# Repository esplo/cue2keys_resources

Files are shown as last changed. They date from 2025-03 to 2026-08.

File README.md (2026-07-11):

# cue2keys_resources

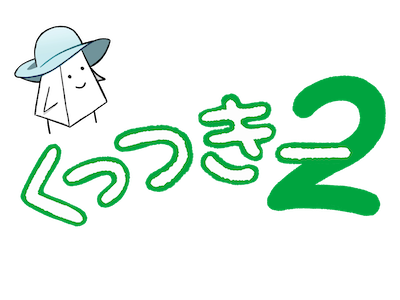
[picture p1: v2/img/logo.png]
ロゴ


このリポジトリでは、[くっつきー](https://cue2keys.esplo.net/)のドキュメントやその他リソースを保管しています。

ここではくっつきーv2のドキュメントを紹介しています。
[初代くっつきーのドキュメントはこちら](./v1/)をご覧ください。

## くっつきーについて知りたい

[紹介記事](https://www.esplo.net/ja/products/cue2keys2)、[公式サイト](https://cue2keys.esplo.net/)や[ビルドガイド](./v2/docs/build_guide.md)をご覧ください。

## 何を組み合わせればよいか知りたい

[購入ガイド](./v2/docs/shopping_guide.md)をご確認ください。

## 購入したので組み立てを知りたい

[ビルドガイド](./v2/docs/build_guide.md)をご覧ください。

## 感想・不具合報告・要望を伝えたい

[SNS](https://x.com/cue2keys)、[マシュマロ](https://marshmallow-qa.com/9p7qcrd1b86zk8d)、このリポジトリの[issue](https://github.com/esplo/cue2keys_resources/issues)、[BOOTHのメッセージ](https://c2k.booth.pm/)などでご連絡ください。

## 挙動を調整したい

くっつきー2用Webアプリをご利用ください。
利用方法はアプリに記載の案内、[ビルドガイド](./v2/docs/build_guide.md)などをご覧ください。

https://app-cue2keys.esplo.net

## リソース一覧

- [ビルドガイド](./v2/docs/build_guide.md)
- [購入ガイド](./v2/docs/shopping_guide.md)
- [困ったときは？](./v2/docs/troubleshoot.md)

- [初代ユーザー向けガイド](./v2/docs/first_user_guide.md)

- [カスタマイズガイド](./v2/docs/customize_guide.md)
- [ファームウェアガイド](./v2/docs/firmware_guide.md)
- [制限・制約](./v2/docs/limits.md)
- [3Dモデル](./v2/docs/models.md)

モジュールの詳細

- [キーモジュール](./v2/docs/modules/keys.md)
- [ディスプレイモジュール](./v2/docs/modules/display.md)

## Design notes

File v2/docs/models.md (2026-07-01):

# 3Dモデル

このページでは、各モジュールの3Dモデルへのリンクをまとめています。
3Dプリンターをお持ちであれば、色変更や交換・カスタマイズなどにご利用ください。

なお、全てネジ不要のはめ込み式なので、フィラメント以外の部品は必要ありません。

## 各モデルへのリンク

全てMakerWorldで公開しています。

- [キー](https://makerworld.com/en/models/2669850-cue2keys-2-key-module-case#profileId-2954925)
- [トラックボール](https://makerworld.com/en/models/2669982-cue2keys-2-trackball-module-case#profileId-2955072)
- [ペンダント](https://makerworld.com/en/models/2978841-cue2keys-2-pendant-module-case#profileId-3341880)
- [ハブ](https://makerworld.com/en/models/2978872-cue2keys-2-hub-module-case#profileId-3341919)
- [ディスプレイ](https://makerworld.com/en/models/2978860-cue2keys-2-display-module-case#profileId-3341903)
- [ノブ](https://makerworld.com/en/models/2978908-cue2keys-2-rotary-encoder-module-case#profileId-3341963)
- [土台](https://makerworld.com/en/models/2978887-cue2keys-2-base#profileId-3341940)
- [土台ケース](https://makerworld.com/en/models/2978878-cue2keys-2-base-case#profileId-3341930)
- [チップ](https://makerworld.com/en/models/2997135-cue2keys-2-chip#profileId-3364564)

## 印刷のTips

- 土台と接触する凹凸部分は、0.12mm以下のLayer heightで印刷してください。Layer Height Modifierを使うと、対象部分だけ個別にLayer heightを設定できます。

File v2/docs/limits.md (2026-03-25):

# モジュール接続の制約

くっつきー2では、モジュールをケーブルで接続することで、数を自由に増減できます。
ただし、基板・電気およびソフトウェアによる制限があります。
このページでは、その詳細を記載します。

## まとめ

最初に簡単なまとめを記載します。
状況により個数は変わるため、一般的な上限値を記載します。
詳細は各項目をご覧ください。

- 最低限動作に必要: ペンダントx1、ハブx1
- ハブ: 最大4つ
- トラックボール: 最大4つ
- キー・マグネキーモジュール合計: 40個
- マグネキーモジュール: （最大精度）10個程度
- 1つのハブ:
  - 最大14個のキー・マグネキー・ノブ・ディスプレイ
  - 1つのトラックボールモジュール
- ノブ: 最大16個
- ディスプレイ: 最大1個
- 初代モジュール:
  - 4キー/5キー/ノブの制約は初代と同じ
  - トラックボールは2の制約と同じ
  - 1つのハブに対し1つの変換モジュールが必要

処理コストが一定を超えると、1秒間に処理できる入力の頻度が減り、タイピングおよびマウスカーソル移動がカクつくようになってしまいます。
マグネキーなど処理の重いモジュールを負荷の高い設定で利用する場合、後述する`処理コストの目安`を参考にしてください。

### 基礎知識

- ペンダントは4つのチャンネルを持つ
- 各チャンネルにはそれぞれ別のハブを接続する
- チャンネル単位での制約、ハブ単位の制約、全体の制約がそれぞれあることに注意

## モジュールごとの制約

### キーの制約

1つのハブにつき、最大14個まで接続できます。
マグネキーは読み取りに時間がかかるため、後述する`処理コストの目安`を参考にしてください。

### ディスプレイの制約

全体で最大1つです。

### トラックボールの制約

1つのチャンネルにつき1つ、全体で4つまで接続できます。
接続にはハブが必要で、1つのハブに1つだけ接続できます。

### ハブの制約

基板には4pinコネクターが14個、6pinコネクターが2個あります。
ただし、6pinコネクターにはどちらか片方のみ接続できます。

物理的に遠い距離に置きたい（左右分割）、別チャンネルを使いたい場合は、複数のハブが必要です。

ハブはカスケード接続をして複数のハブを直列につなぐことも可能ですが、初代モジュール接続以外では非推奨です。

## 処理コストの目安

1秒間に処理できる入力の回数（スキャンレート）は、接続しているモジュールの数や種類によって大きく変動します。
特にマグネキーは高い精度で利用すると処理時間がかかりますので、多く繋ぐ場合はご注意ください。

記載外モジュールの影響（ディスプレイ・トラックボール）、ファームウェアのバージョンやトラックボールの操作有無により変動するため、下記の値は目安としてご利用ください。

- キーモジュール: 0.15ms
- マグネキーモジュール（12bit設定）: 0.27ms
- マグネキーモジュール（8bit設定）: 0.22ms
- マグネキーモジュール（4bit設定）: 0.17ms
- マグネキーモジュール（2bit設定）: 0.15ms
- ロータリーエンコーダー: 0.13ms

なお、スターターセットDXの構成では377回/秒（2.65ms）程度、トラックボールを動かすと347回/秒（2.88ms）となっています。

### 様々な例

ここでは、構成によってスキャンレートがどの程度になるかの例を記載します。
ファームウェアバージョンや操作（トラックボールを動かしたかどうか）で変動しますので、あくまで目安としてご利用ください。

ご要望に応じて追記します。
組み合わせによってはお時間をいただくかもしれませんが、お気軽にご連絡ください。

- （スターターセットDX） キー14個、マグネキー1個、ディスプレイ、ノブ、トラックボール: 377回/秒
-  キー10個、マグネキー6個（12bit）、ディスプレイ、ノブ、トラックボール: 308回/秒

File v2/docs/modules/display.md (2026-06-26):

# ディスプレイモジュール詳解

https://c2k.booth.pm/items/8105221

## 新旧バージョンの違い

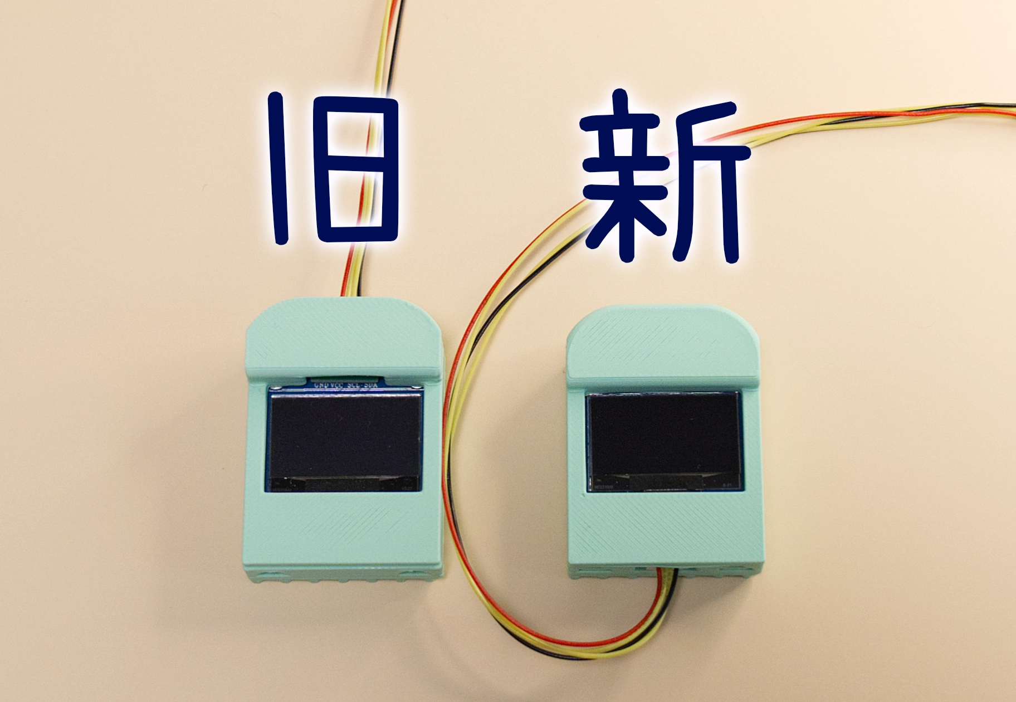
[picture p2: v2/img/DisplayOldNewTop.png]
両バージョン


キーケット後のバージョンでは、製造都合により基板とケースが変更になっております。悪しからずご了承ください。

新バージョンではケーブルが下部から出ているほか、少しだけ高さが減っていたり、ケーブルを通しやすくなっています。

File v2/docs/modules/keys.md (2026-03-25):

# キーモジュール詳解

https://c2k.booth.pm/items/8027041

## キースイッチの変更

一般的なキースイッチプーラーなどを使い、スイッチを取り外して変更してください。

通常キーモジュールは、5pinまたは3pinのCherry MXキースイッチに対応しています。
また、マグネキーモジュールは、KS-20互換であれば動作します。他のキースイッチでも形状が合えば設定で対応できると思いますが、公式サポートにはなりません。小数のキーで試してから入れ替えをお勧めします。

## 分解・組み立て

### 必要な状況

- キー数を減らしたい（最小2キー、最大4キーで動作します）
- トラブルシューティング・メンテナンス

## 手順

キーモジュールのケースを変えたい場合やケーブルの接続を変更したい場合、キーの数を変えたい場合はこの手順に従ってください。

キーモジュールは小さいパーツが多く、分解・組み立てには注意が必要です。時間もかかるため、余裕のあるときに行いましょう。

### 用意するもの

- なるべく細いマイナスドライバー

### 分解方法

各キーを接続しているFPCケーブルを外します。

FPCケーブルはFPCコネクターで留められています。
青色のストッパーを上げてケーブルを引き抜くことで外せます。
ケースの背面にある隙間から、マイナスドライバーを使って外してください。

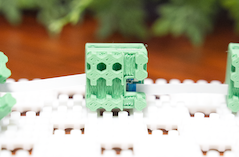
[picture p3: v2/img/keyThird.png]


ケーブルが外せたら、基板をスライドして取り出します。
通常キーモジュールではキーソケットで固定されているので、上方向に押し上げる必要があります。

3,4キーは外しても動作しますが、1,2キーは動作に必須です。

### 組み立て

分解と逆の手順を行います。

まずは基板をケースに格納します。
特にマグネキーでは、向きを間違えないようにしてください。

FPCケーブルは、ケースの裏側から見て青色の部分が上に来るようにして接続をすると楽です。両端を同じ方向で留める必要があります。

2,3,4キーに関しては、スリットを通して前のキーからFPCケーブルを通し、内部でコネクタに差し込む必要があります。
この作業は手先の器用さが問われます。
なるべく細いマイナスドライバーを使い、誘導したうえで青色のカバー部分を押し込み、ストッパーを下ろすとやりやすいです。
青色の部分は厚みがあり硬いので、そこをマイナスドライバーで押してコネクタの奥に差し込みます。十分に差し込まれたと思ったら、青色のストッパーを下げて固定します。

1キーは、4pinSHケーブルを繋いでから基板をケースに格納します。

> [!TIP]
> ストッパーを上げてからケースに入れると楽です。
> 
> スリットを通す必要があるケーブルを先につないでおくと楽です。
> 4キーから順番に作っていくとスムーズに進みやすいです。

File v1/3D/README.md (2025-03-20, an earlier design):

# 3Dモデル

くっつきーで使用されているケース・接続パーツの3Dモデルを公開しています。
破損時に印刷したり、カスタマイズなどにご利用ください。

なお、正常な動作や最新のものであることを保証するものではありません。
ご注意ください。

## 穴の仕様

穴の距離は、`4.75mm`に統一されています。
凸部分は直径`3.05mm`、凹部分は直径`3.07mm`で設定しています。

高い成形精度がある場合はこの設定で問題ないことが多いですが、家庭用3Dプリンタなど精度が出にくい場合は穴のサイズを変更してください。
参考までに、制作者の環境では凹に`0.2mm`を追加するとはまりやすくなりました。

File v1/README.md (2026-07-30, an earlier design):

# cue2keys_resources

こちらは初代くっつきーのドキュメントです。
最新版は[こちら](./README.md)をご覧ください。

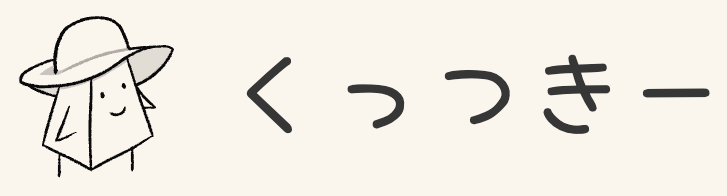
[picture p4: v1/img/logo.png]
ロゴ


このリポジトリには、[くっつきー](https://cue2keys.esplo.net/)のドキュメントやその他リソースを保管しています。

## くっつきーについて知りたい

[公式サイト](https://cue2keys.esplo.net/)や[ビルドガイド](./docs/build_guide.md)をご覧ください。

## 何を組み合わせればよいか知りたい

[ビルドガイドの購入ガイド](./docs/build_guide.md)をご確認ください。

## 挙動を調整したい

[カスタムキーコード](./docs/custom_keycodes.md)、[キーマップガイド](./docs/keymap_guide.md)などをご覧ください。

## 不具合報告・要望を伝えたい

各種SNS、[マシュマロ](https://marshmallow-qa.com/9p7qcrd1b86zk8d)、このリポジトリの[issue](https://github.com/esplo/cue2keys_resources/issues)などでご連絡ください。

## リソース一覧

- [3Dモデル](./3D/)
- [ビルドガイド](./docs/build_guide.md)
- [FAQ](./docs/faq.md)
- [カスタマイズガイド](./docs/customize_guide.md)
- [ファームウェアガイド](./docs/firmware_guide.md)
- [キーマッピングガイド](./docs/keymap_guide.md)
- [回路データ](./circuits.md)

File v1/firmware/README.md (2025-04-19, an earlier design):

# ファームウェア

詳細は[ファームウェアガイド](../docs/firmware_guide.md)をご覧ください。

ここでは、ベストエフォートで更新履歴を記載してゆきます。

## バージョン履歴

### 20250419-1.2.0

**このファームウェア以降に更新する場合、[ファームウェアガイド](../docs/firmware_guide.md)に従い設定値をリセットしてください。**

- 設定可能なパラメーターを追加・変更
    - オートマウスレイヤーの有効・無効切り替えが可能に
    - マウスレイヤー変更への遅延時間が6,300msまで設定可能に
    - トラックボールの角度調整が1°単位で可能に
    - マウスポインターの移動速度が幅広く設定可能に
    - ドラッグスクロールの左右・上下反転が可能に
    - ドラッグスクロールの速度変更が可能に
    - 全てのキー入力をマウスキーとして扱うことが可能に
    - ロータリーエンコーダーの解像度変更が可能に（変更後再起動すると有効）
- ディスプレイにバージョン情報を表示するページを追加

パラメーターの詳細は、[カスタムキーコード](../docs/custom_keycodes.md)をご覧ください。

### 20250329-1.1.1

- ドラッグスクロール（押している間はトラックボールの動きがスクロールになる）機能を追加
    - カスタムキーコード `DRAG_SCROLL` を押している間の動作

### 20250323-1.1.0

**このファームウェア以降に更新する場合、[ファームウェアガイド](../docs/firmware_guide.md)に従い設定値をリセットしてください。**

- トラックボールへの振動でマウスレイヤーが有効になる問題に対処
- カスタムキーコードの変更
    - `MOUSE_LAYER_MS_*_100MS` -> `MOUSE_LAYER_MS_*_50MS` に名称が変わり、250msから1000msで50ms単位での設定に

### 20250312-1.0.1

- マウスポインターの移動速度調整機能を追加
- カスタムキーコードを追加
    - NEXT_OLED_PAGE
        - OLEDのページをめくる
    - POINTER_SPEED_MAG_CHANGE
        - マウスポインターの移動速度倍率を設定する
        - 0 (0.5x)、1 (1.0x)、2 (2.0x)、3 (4.0x)
- デフォルトキーマップを一部変更

### 20250222-1.0.0

初期バージョン

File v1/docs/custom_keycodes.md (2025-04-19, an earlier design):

# カスタムキーコードの説明

このファイルは、キーボードファームウェアで使用されるカスタムキーコードについて説明します。

## 設定変更キーコード

以下のキーコードは、キーボードの設定値を変更するために使用されます。

| キーコード名 | HEXコード | 設定値名 | 説明 | 変更量 | 最大値 | デフォルト値 |
|---|---|---|---|---|---|---|
| `AUTO_MOUSE_LAYER_P1` | `0x7E02` | `mlo` | 自動マウスレイヤー (有効/無効) | `1` | `1` | `1` |
| `AUTO_MOUSE_LAYER_OFF_DELAY_P1` | `0x7E03` | `mod` | 自動マウスレイヤーオフの遅延時間 (ミリ秒、値 * 100ms) | `1` | `63` | `13` |
| `AUTO_MOUSE_LAYER_OFF_DELAY_M1` | `0x7E04` | `mod` | 自動マウスレイヤーオフの遅延時間 (ミリ秒、値 * 100ms) | `-1` | `63` | `13` |
| `ANGLE_L_ADJUSTMENT_P1` | `0x7E05` | `agl` | トラックボールの角度調整 (左側) | `1` | `359` | `0` |
| `ANGLE_L_ADJUSTMENT_M1` | `0x7E06` | `agl` | トラックボールの角度調整 (左側) | `-1` | `359` | `0` |
| `ANGLE_L_ADJUSTMENT_P30` | `0x7E07` | `agl` | トラックボールの角度調整 (左側) | `30` | `359` | `0` |
| `ANGLE_L_ADJUSTMENT_M30` | `0x7E08` | `agl` | トラックボールの角度調整 (左側) | `-30` | `359` | `0` |
| `ANGLE_R_ADJUSTMENT_P1` | `0x7E09` | `agr` | トラックボールの角度調整 (右側) | `1` | `359` | `0` |
| `ANGLE_R_ADJUSTMENT_M1` | `0x7E0A` | `agr` | トラックボールの角度調整 (右側) | `-1` | `359` | `0` |
| `ANGLE_R_ADJUSTMENT_P30` | `0x7E0B` | `agr` | トラックボールの角度調整 (右側) | `30` | `359` | `0` |
| `ANGLE_R_ADJUSTMENT_M30` | `0x7E0C` | `agr` | トラックボールの角度調整 (右側) | `-30` | `359` | `0` |
| `POINTER_SPEED_MAGNIFICATION_P1` | `0x7E0D` | `psm` | ポインター速度倍率 (値 * 0.25) | `1` | `15` | `4` |
| `POINTER_SPEED_MAGNIFICATION_M1` | `0x7E0E` | `psm` | ポインター速度倍率 (値 * 0.25) | `-1` | `15` | `4` |
| `INVERT_DRAG_SCROLL_X_P1` | `0x7E0F` | `idsX` | ドラッグスクロールのX軸方向を反転 (有効/無効) | `1` | `1` | `0` |
| `INVERT_DRAG_SCROLL_Y_P1` | `0x7E10` | `idsY` | ドラッグスクロールのY軸方向を反転 (有効/無効) | `1` | `1` | `0` |
| `DRAG_SCROLL_SPEED_MAGNIFICATION_P1` | `0x7E11` | `dsm` | ドラッグスクロール速度倍率 (値 * 0.25) | `1` | `15` | `4` |
| `DRAG_SCROLL_SPEED_MAGNIFICATION_M1` | `0x7E12` | `dsm` | ドラッグスクロール速度倍率 (値 * 0.25) | `-1` | `15` | `4` |
| `TRACKBALL_LED_OFF_TIMEOUT_P1` | `0x7E13` | `tlt` | トラックボールLED消灯タイムアウト (なし, 5分, 10分, 15分) | `1` | `3` | `1` |
| `TRACKBALL_LED_OFF_TIMEOUT_M1` | `0x7E14` | `tlt` | トラックボールLED消灯タイムアウト (なし, 5分, 10分, 15分) | `-1` | `3` | `1` |
| `ALL_KEYS_ARE_MOUSE_KEYS_P1` | `0x7E15` | `amk` | 全てのキー入力をマウスキーとして扱う (有効/無効) | `1` | `1` | `0` |
| `ROTARY_ENCODER_1_RESOLUTION_P1` | `0x7E16` | `rr1` | ロータリーエンコーダー1の解像度 (反映には再起動が必要) | `1` | `3` | `2` |
| `ROTARY_ENCODER_2_RESOLUTION_P1` | `0x7E17` | `rr2` | ロータリーエンコーダー2の解像度 (反映には再起動が必要) | `1` | `3` | `2` |
| `ROTARY_ENCODER_3_RESOLUTION_P1` | `0x7E18` | `rr3` | ロータリーエンコーダー3の解像度 (反映には再起動が必要) | `1` | `3` | `2` |
| `ROTARY_ENCODER_4_RESOLUTION_P1` | `0x7E19` | `rr4` | ロータリーエンコーダー4の解像度 (反映には再起動が必要) | `1` | `3` | `2` |
| `ROTARY_ENCODER_5_RESOLUTION_P1` | `0x7E1A` | `rr5` | ロータリーエンコーダー5の解像度 (反映には再起動が必要) | `1` | `3` | `2` |
| `ROTARY_ENCODER_6_RESOLUTION_P1` | `0x7E1B` | `rr6` | ロータリーエンコーダー6の解像度 (反映には再起動が必要) | `1` | `3` | `2` |
| `ROTARY_ENCODER_7_RESOLUTION_P1` | `0x7E1C` | `rr7` | ロータリーエンコーダー7の解像度 (反映には再起動が必要) | `1` | `3` | `2` |
| `ROTARY_ENCODER_8_RESOLUTION_P1` | `0x7E1D` | `rr8` | ロータリーエンコーダー8の解像度 (反映には再起動が必要) | `1` | `3` | `2` |
| `ROTARY_ENCODER_9_RESOLUTION_P1` | `0x7E1E` | `rr9` | ロータリーエンコーダー9の解像度 (反映には再起動が必要) | `1` | `3` | `2` |
| `ROTARY_ENCODER_10_RESOLUTION_P1` | `0x7E1F` | `rr10` | ロータリーエンコーダー10の解像度 (反映には再起動が必要) | `1` | `3` | `2` |
| `ROTARY_ENCODER_11_RESOLUTION_P1` | `0x7E20` | `rr11` | ロータリーエンコーダー11の解像度 (反映には再起動が必要) | `1` | `3` | `2` |
| `ROTARY_ENCODER_12_RESOLUTION_P1` | `0x7E21` | `rr12` | ロータリーエンコーダー12の解像度 (反映には再起動が必要) | `1` | `3` | `2` |
| `ROTARY_ENCODER_13_RESOLUTION_P1` | `0x7E22` | `rr13` | ロータリーエンコーダー13の解像度 (反映には再起動が必要) | `1` | `3` | `2` |
| `ROTARY_ENCODER_14_RESOLUTION_P1` | `0x7E23` | `rr14` | ロータリーエンコーダー14の解像度 (反映には再起動が必要) | `1` | `3` | `2` |
| `ROTARY_ENCODER_15_RESOLUTION_P1` | `0x7E24` | `rr15` | ロータリーエンコーダー15の解像度 (反映には再起動が必要) | `1` | `3` | `2` |
| `ROTARY_ENCODER_16_RESOLUTION_P1` | `0x7E25` | `rr16` | ロータリーエンコーダー16の解像度 (反映には再起動が必要) | `1` | `3` | `2` |

## その他のカスタムキーコード

| キーコード名  | 説明 |
|---|---|
| `NEXT_OLED_PAGE` | OLEDディスプレイの表示ページを次に切り替えます。 |
| `DRAG_SCROLL` | ポインティングデバイスの動きをスクロール操作に切り替えます（ドラッグスクロール）。 |

## 設定値の確認方法

OLEDディスプレイの2ページ目以降で確認できます。
NEXT_OLED_PAGEを活用すると、ペンダント本体のボタンを押さずともページを変更できます。

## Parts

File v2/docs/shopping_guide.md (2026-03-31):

# くっつきー2 購入ガイド



くっつきー2の世界へようこそ！

このドキュメントはくっつきー2の購入ガイドです。

## 概要

くっつきー2はフルモジュラー式のキーボードです。
各パーツはモジュールとなり、好きな数、位置に配置することができます。

特徴の詳細は、下記の記事をご覧ください。

https://www.esplo.net/ja/posts/2026/02/cue2keys2

下記のページにリンクをまとめています。

https://www.esplo.net/ja/products/cue2keys2

最新情報はSNSをご覧ください。

https://x.com/cue2keys

## V2で対応しているモジュール

- [キーモジュール](https://c2k.booth.pm/items/8027041)（最大4キー、メカニカルスイッチ）
- [マグネキーモジュール](https://c2k.booth.pm/items/8027041)（最大4キー、磁気スイッチ）
- [ロータリーエンコーダー（ノブ）](https://c2k.booth.pm/items/8092543)
- [トラックボール](https://c2k.booth.pm/items/8090670)
- [ディスプレイ](https://c2k.booth.pm/items/8105221)

### 接続用モジュール

- [ハブ](https://c2k.booth.pm/items/8092567)
- [ペンダント](https://c2k.booth.pm/items/8092877)
- [土台](https://c2k.booth.pm/items/8092741)
- [土台ケース](https://c2k.booth.pm/items/8092741)

### 初代の互換モジュール

初代くっつきーをお持ちの方は、初代の下記モジュールもつなぐことができます。

- 4キーモジュール
- 5キーモジュール
- 初代ロータリーエンコーダー
- 初代トラックボール

ただし、ケーブルが異なるため変換モジュールが必要です。
それぞれのモジュールの詳細はリンク先をご覧ください。

## 購入ガイド

「この構成で動くの？」

悩んだら、[制約ガイド](./limits.md)などを参照しつつ、お気軽にSNSなどでご相談ください。

### 迷ったら？

おすすめはスターターセットです。

動作に必要なモジュール一式が揃い、56キーの左右分割キーボードが組み立てられます。
DXセットでは、追加で磁気キースイッチ対応モジュール4キー分、トラックボール、ノブ、ディスプレイが付属します。

スターターセットには、さらにキーやノブを追加することができます。また、スターターセットの一部を使ってテンキーを作成するといったこともできます。

https://c2k.booth.pm/items/7753347

### 最小限で組んでみたい

最低限動作に必要なものは、ペンダントとハブです。
これにキーモジュールやノブ、トラックボールを付けることで動作します。
左右で分割をしたい場合は、ハブを2つにします。

別途固定する方法が必要です。無い場合は土台をを追加し、その上に配置をしてください。

これらを踏まえ、例えばテンキー（全16キー）を土台付きで作成すると、次のような構成になります。

- ペンダントx1
- ハブx1
- キーモジュールx4
- 土台x1

### 片手デバイスとして使いたい

クリエイティブ用途に片手デバイスとして使うことも可能です。
例えば次のような構成で作成できます。

- ペンダントx1
- ハブx1
- キーモジュールx2
- ノブx4
- トラックボールx1
- 土台x1

位置を自由に変更できるので、手に合う形にして生産性を上げましょう。

## オンライン販売について

キーケット終了後、予約販売を開始します。
本作は製造に時間がかかるので、セットは注文いただいてからお時間がかかることをご了承ください。

直近のスケジュールとしては、下記の通りです。

- 4月: 予約受け付け（7月発送分）
- 5-6月: 予約受け付け（4月受け付け分以降の発送）
- 7月: 順次発送開始、在庫追加

予約受け付けでおおよその数を見積もり、発注します。
少し多めに発注をするので、予約分から順次発送し、余れば在庫として追加いたします。

### 色について

基本、[ショップページ](https://c2k.booth.pm/items/7753347)に記載のある通り「わかば（明るい緑色、画像の左端）」で統一する予定です。
ただ、長い期間お待たせしてしまうので、ご希望に応じて「わかば」と「くも（白、右から2番目）」との組み合わせも可能とします [^color_change]。

詳細が決まり次第、予約購入後のメッセージ機能にてご連絡いたしますので、ご確認ください。

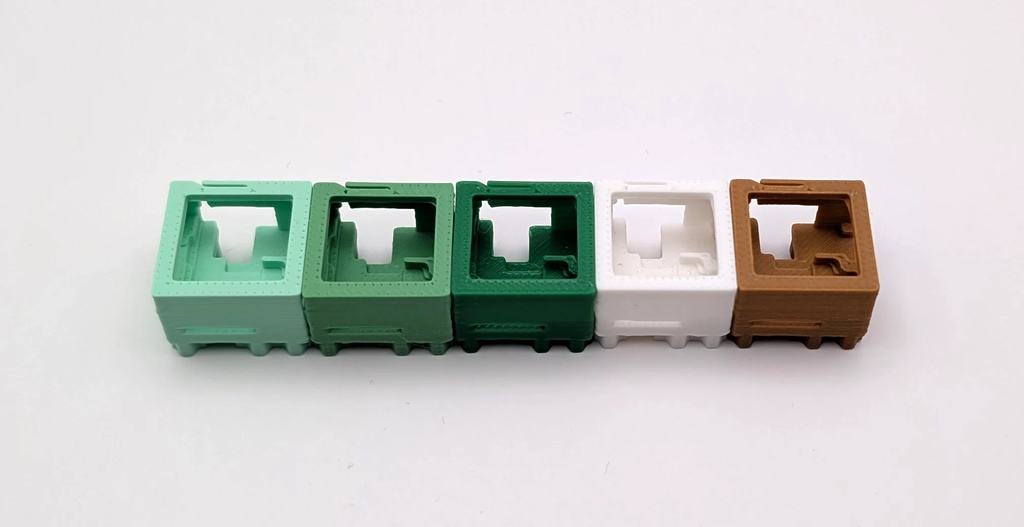
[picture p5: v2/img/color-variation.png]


[^color_change]: おそらく問題ないかと思いますが、製造都合により色が変わる可能性があることもご了承ください（実際、左から2番目の色は商品写真撮影後にフィラメントが終売となってしまいました……）

### 予約後の各種変更について

仕様変更などがあれば、適宜お知らせをします。
ご購入者様側で選択が必要な場合は、ブースのメッセージ機能でご連絡いたします。

### その他

最新情報・詳細はSNSをご覧ください。

https://x.com/cue2keys

基本点があればお気軽にご連絡ください。
よくあるご質問は、本ドキュメントに追記します。

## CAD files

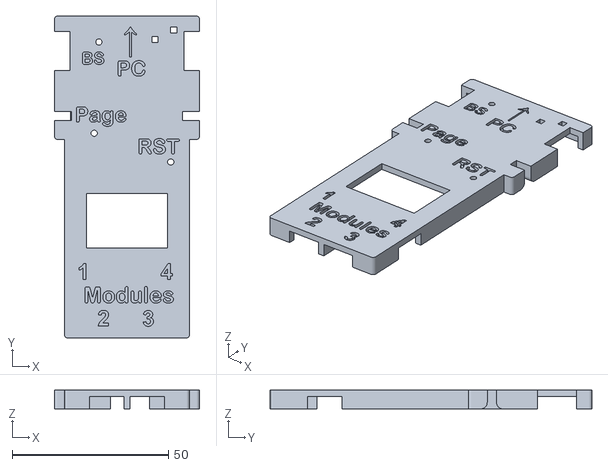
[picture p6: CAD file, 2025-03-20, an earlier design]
v1/3D/pendant-top.stl
46.4 x 103.0 x 6.00

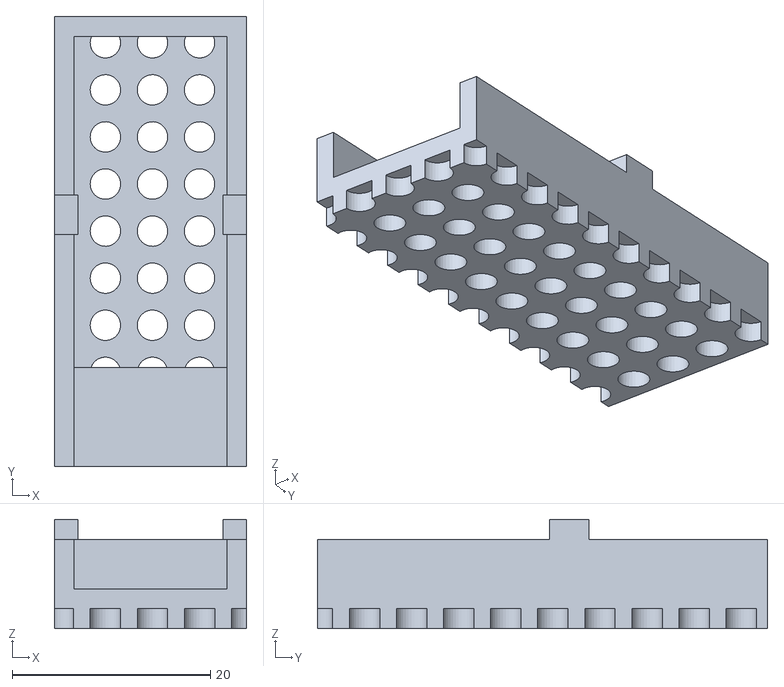
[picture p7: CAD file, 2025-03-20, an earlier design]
v1/3D/knob-bottom.stl
19.4 x 45.4 x 11.0

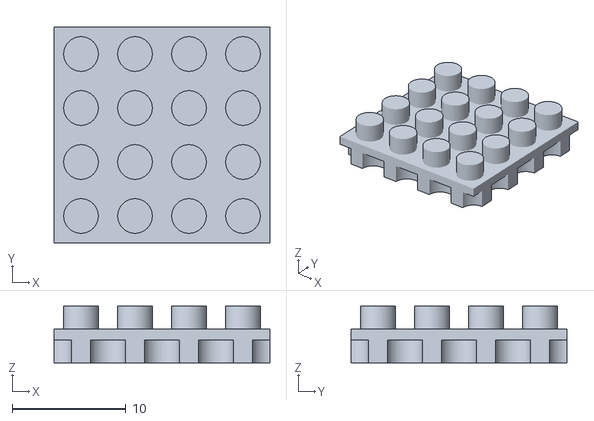
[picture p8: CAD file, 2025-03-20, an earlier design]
v1/3D/chip-flat.stl
19.0 x 19.0 x 5.00

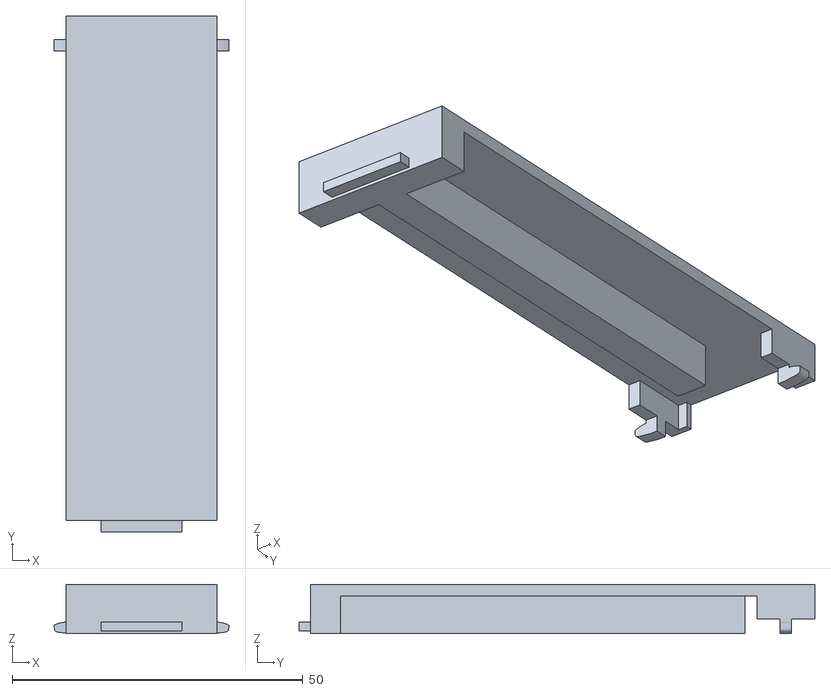
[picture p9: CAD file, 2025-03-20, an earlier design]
v1/3D/hub-top.stl
30.0 x 88.7 x 8.50

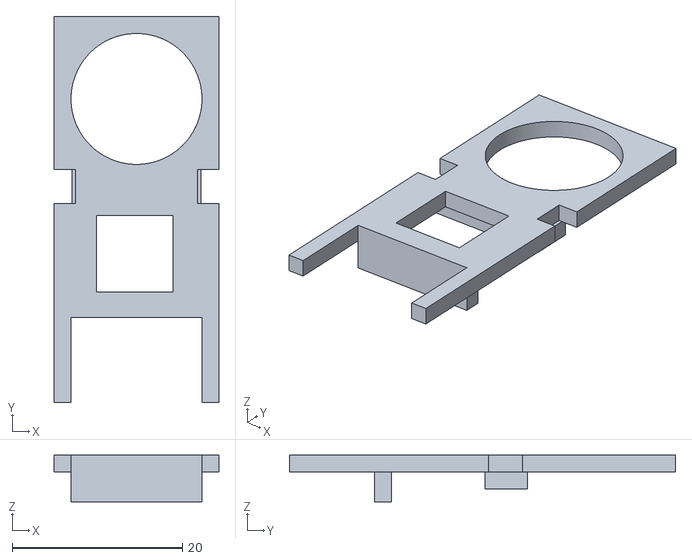
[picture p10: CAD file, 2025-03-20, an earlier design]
v1/3D/knob-top.stl
19.4 x 45.4 x 5.50

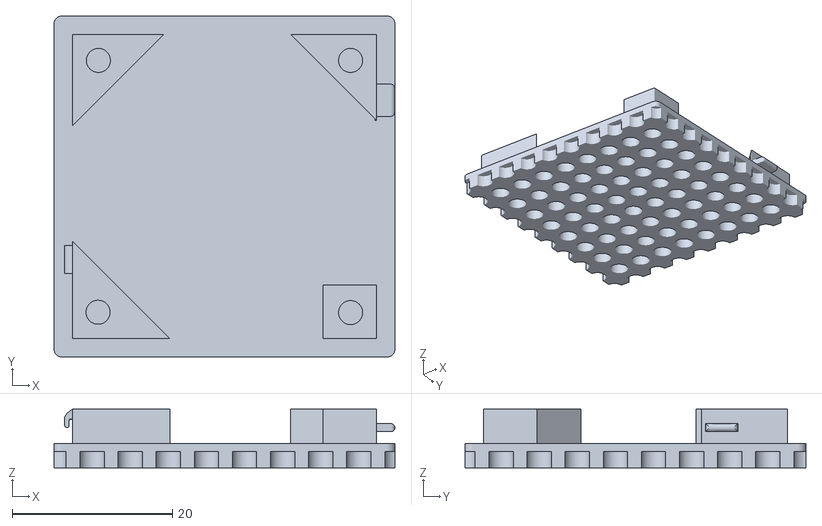
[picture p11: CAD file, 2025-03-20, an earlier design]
v1/3D/trackball-bottom.stl
42.5 x 42.5 x 7.30

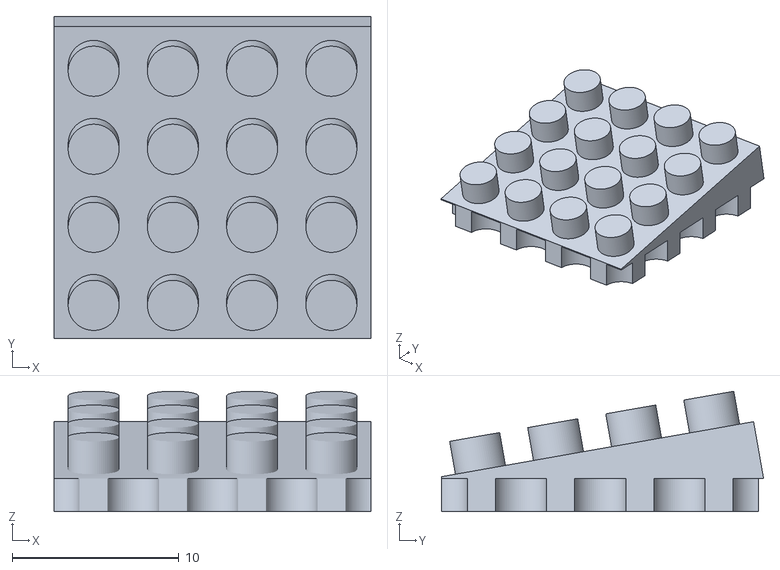
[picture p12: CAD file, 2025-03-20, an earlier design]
v1/3D/chip-10.stl
19.0 x 19.3 x 7.22

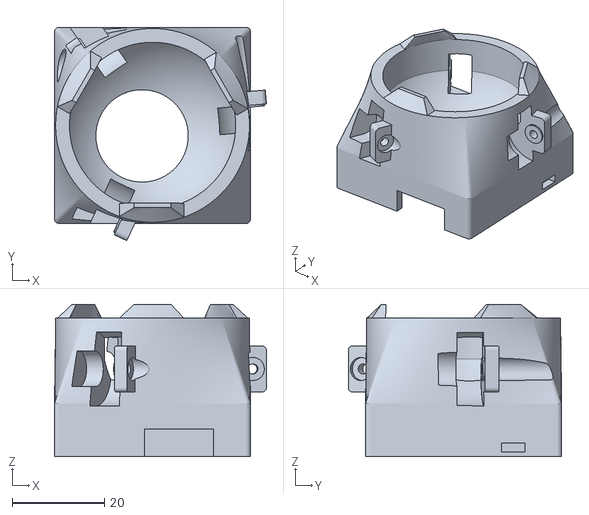
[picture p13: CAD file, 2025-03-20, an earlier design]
v1/3D/trackball-body.stl
45.9 x 46.2 x 33.0

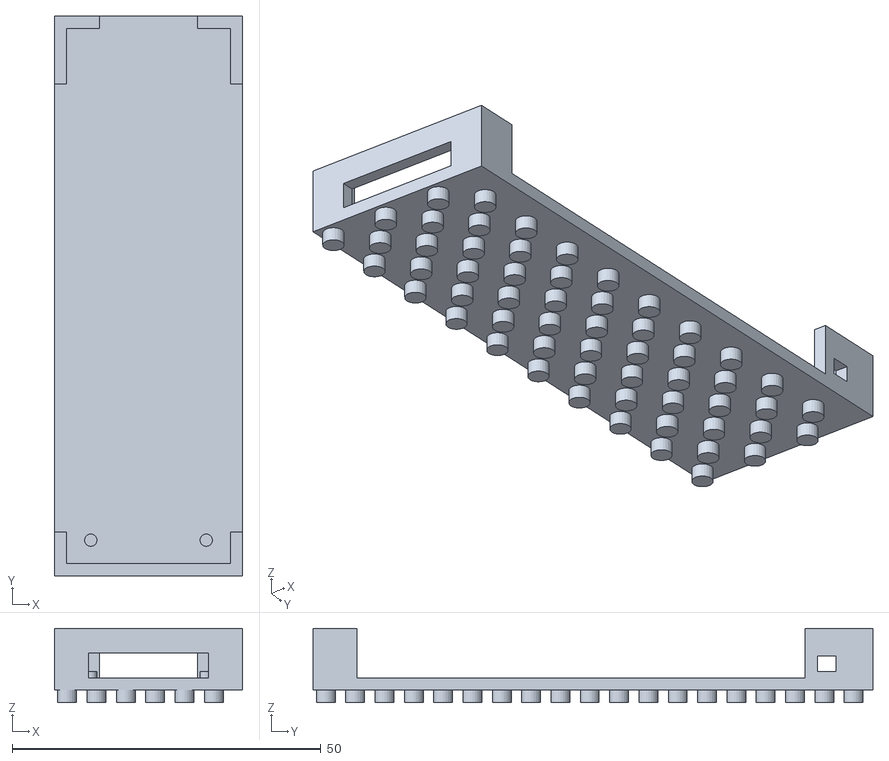
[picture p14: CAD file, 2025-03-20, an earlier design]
v1/3D/hub-bottom.stl
30.5 x 90.7 x 12.0

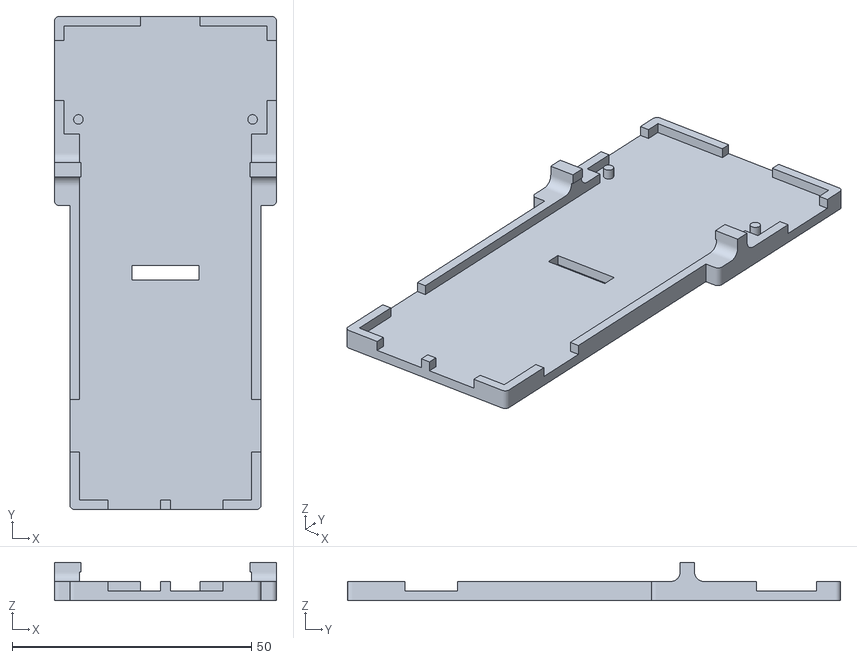
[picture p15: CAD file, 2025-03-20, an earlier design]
v1/3D/pendant-bottom.stl
46.4 x 103.0 x 8.00

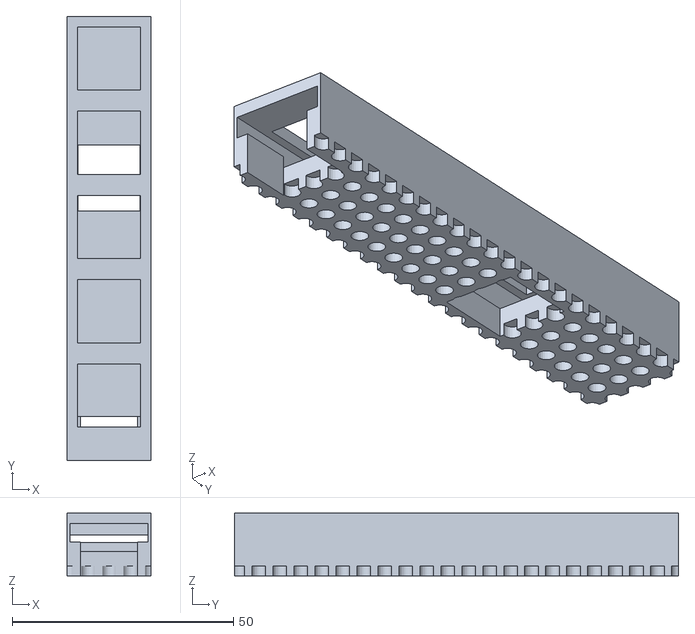
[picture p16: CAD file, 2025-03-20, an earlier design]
v1/3D/key5.stl
19.0 x 100.4 x 14.2

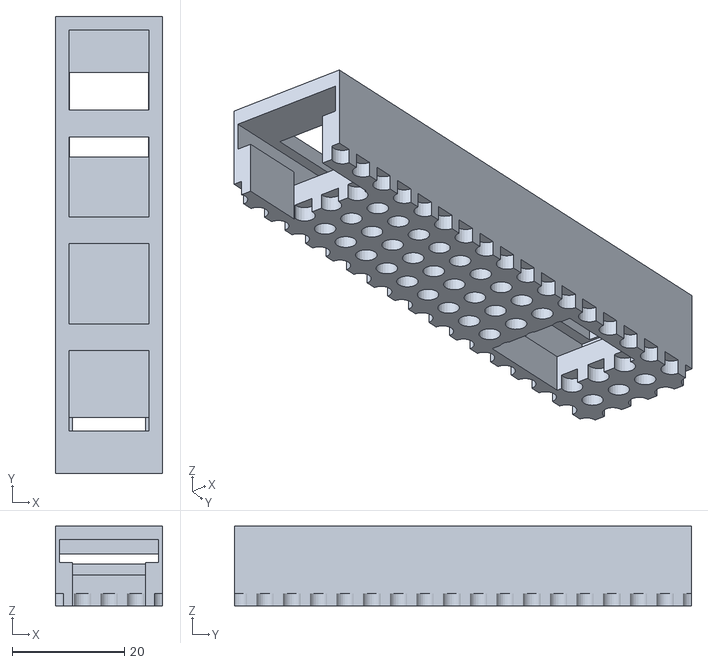
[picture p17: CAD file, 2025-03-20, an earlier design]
v1/3D/key4.stl
19.0 x 81.4 x 14.2

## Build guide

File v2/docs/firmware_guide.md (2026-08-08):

# ファームウェアガイド

このドキュメントでは、くっつきー2で利用しているファームウェアやコードについて紹介します。

なお、改変したコードについてはサポートしかねます。あらかじめご了承ください。

良い変更があれば、GithubでPRを提出いただけますと助かります。

## ファームウェアの書き込み方法

ペンダントのrstボタンは、2回ゆっくりダブルクリックすると書き込み待ち状態になります。
ケースはゆっくり左右に揺らしつつ上にスライドすると外せるので、外して押しても良いですし、ケースの穴から細いピンで押しても良いです。
書き込み待ちになると、rstボタン付近のLEDが光ります。

もしうまく書き込み待ちにならない場合は、PCからケーブルを抜き、btボタンを押しながら接続してしばらく待ってみてください。

PCから外部ストレージとして認識されたら、`.uf2`ファイルをコピー&ペーストします。
自動で再接続されますが、書き込みが完了したら念のためUSBを抜き差ししてください。

ファームウェアは [ファームウェアリポジトリ](https://github.com/cue2keys/v2_qmk_fw/releases/) にて公開しています。

## 全体に関連するリポジトリ

関連するファームウェアを不整合なくビルドするために、下記リポジトリを利用するのがおすすめです。

https://github.com/cue2keys/v2_meta_build

共通スキーマは下記リポジトリに配置しています。

https://github.com/cue2keys/v2_flatcc_schema

それぞれREADMEをご確認の上、ご利用ください。

## ペンダントモジュールのQMKファームウェア

下記のリポジトリにてキーボード実装のコードを公開しています。

Releaseにビルド済みファームウェアを公開しているほか、READMEをご確認の上、ビルドして利用・改変いただけます。

https://github.com/cue2keys/v2_qmk_fw

## モジュールのファームウェア

キーモジュール、マグネキーモジュール、ノブモジュールについては、CH32V006用のファームウェアを公開しています。

https://github.com/cue2keys/v2_module_fw

書き込みにはWCH-LinkEが必要です。
改変したファームウェアを利用したい場合は、READMEに従いビルドして書き込んでください。

## Webアプリのコード

下記にてWebアプリのコードを公開しています。
インターネット環境が使えない場合でも、こちらをローカルで動かすことで利用する、といった使い方もできます。

https://github.com/cue2keys/v2_web_app

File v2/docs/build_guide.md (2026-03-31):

# くっつきー2 ビルドガイド



くっつきー2の世界へようこそ！

このドキュメントはくっつきー2のビルドガイドです。
購入ガイドはこちらをご覧ください。

## 概要

くっつきー2はフルモジュラー式のキーボードです。
各パーツはモジュールとしてケーブルで接続し、好きな数、位置に配置することができます。

特徴の詳細は、下記の記事をご覧ください。

https://www.esplo.net/ja/posts/2026/02/cue2keys2

下記のページにリンクをまとめています。

https://www.esplo.net/ja/products/cue2keys2

最新情報はSNSをご覧ください。

https://x.com/cue2keys

## V2で対応しているモジュール

- キーモジュール（最大4キー、メカニカルスイッチ）
- マグネキーモジュール（最大4キー、磁気スイッチ）
- ロータリーエンコーダー
- トラックボール
- ディスプレイ

### 接続用モジュール

- ハブ
- ペンダント
- 土台
- 土台ケース

### 初代の互換モジュール

初代くっつきーをお持ちの方は、初代の下記モジュールもつなぐことができます。

- 4キーモジュール
- 5キーモジュール
- 初代ロータリーエンコーダー
- 初代トラックボール

ただし、変換モジュールが必要です。
詳細は[初代ユーザー向けガイド](./first_user_guide.md)をご覧ください。

## 制約

接続できるモジュールの数や種類には、いくつか制約があります。
詳細は[制約ページ](./limits.md)に記載をしているので、必要になった際にご確認ください。

ご不明点はお気軽にご相談ください。

## ビルドガイド

### 準備

モジュールが揃ったら、組み立てと初期設定を行います。
ここからは[スターターセット DX](https://c2k.booth.pm/items/7753347)を購入したものとして進めます。

まずは付属品が揃っているかご確認ください。
スターターセット DXの場合は、下記の通りです。
他のセットの場合は、各商品ページをご覧ください。

- キーモジュール x14（赤いキースイッチが目印）
- マグネキーモジュール x1 （緑のキースイッチが目印）
- トラックボール x1
- ノブ x1
- ディスプレイ x1
- ハブ x2
- ペンダント x1
- 土台 x2
- 滑り止めシール x8粒
- 土台ケース x2

用意するものは次の通りです。

- キーキャップ
- (トラブルシューティング用) 細いマイナスドライバー
- 初期設定用の他キーボード（ラップトップPC）
- インターネット回線
- Chrome系Webブラウザー（現在Firefox/Safariでは動作しません。お手数ですが、Chrome系ブラウザをインストールしご利用ください）

うまくいかない箇所があれば、[トラブルシューティングガイド](./troubleshoot.md)を適宜参照ください。

### Step0: 理想の配置を考える

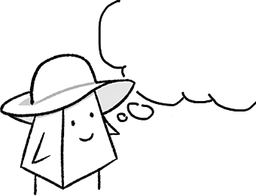
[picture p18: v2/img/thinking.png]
thinking


まずは理想の配置を考えましょう。
どのような物理レイアウトがいいのか、キーやトラックボールの位置はどのあたりが良いのかなど、利用シーンを思い描いて考えてみましょう。
一度決めたレイアウトも後から変更できます。

大体のイメージが固まったら、最終的にその形に変更すること考えつつ、一度保留します。

まずは動作確認のため、片手に7キーを持つカラムスタッガード配列で組み進めます。
無事動作確認ができたら、理想の配列や調整を試してみましょう。

### Step1: ペンダントの接続確認

まずは最低限の接続をして動作確認をしてみましょう。
PCとペンダントモジュールをUSBケーブルで接続します。

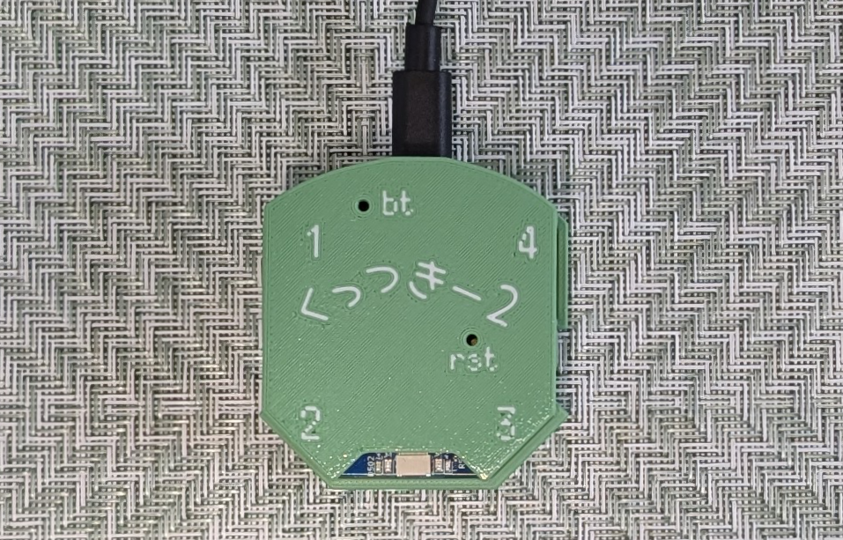
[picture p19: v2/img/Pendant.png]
Pendant


その後、Chromeブラウザー[^chrome]で下記のページにアクセスします。

[^chrome]: Chromiumベースのブラウザでも動作します。Chrome/Edge/Vivaldi/Braveなど。

https://app-cue2keys.esplo.net/

「接続」を押すと、次のようなダイアログが出てきます。
もし出てこない場合は、USBケーブルを差し直して少し待ってから再度確認してみてください。
また、接続する際に使うUSBポートも変更して試してみてください。

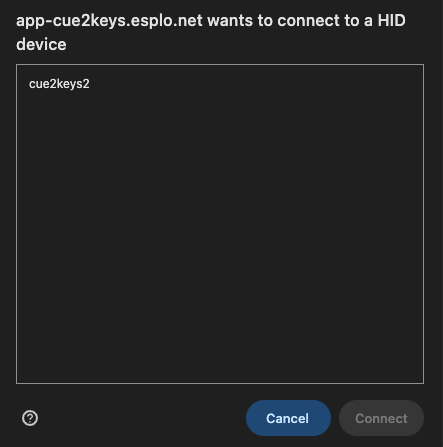
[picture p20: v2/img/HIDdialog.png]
HIDdialog


選択して接続をすると、次のような画面が出ます。

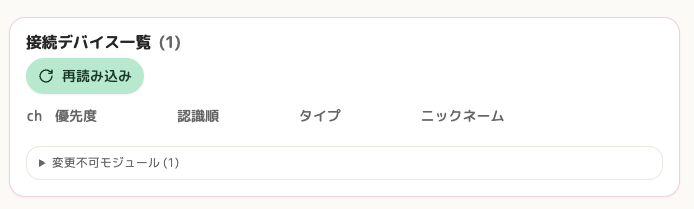
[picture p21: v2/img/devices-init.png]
devices-init


ペンダントのみを接続した状態では、他に接続されているモジュールがないため、このような表示になります。なお、内部的にペンダントに接続しているモジュールが`1`として表示されています。

このようにWebアプリから接続デバイスを確認できます。
この手順は以降繰り返し実施します。

#### ファームウェアの更新

ペンダントのファームウェアが最新でない場合には更新をしてください。
これは「その他」メニューで確認できます。

最新版のファームウェアがある場合はGithubへのリンクが表示されます。
`.uf2`ファイルがファームウェアの本体なので、これをダウンロードします。

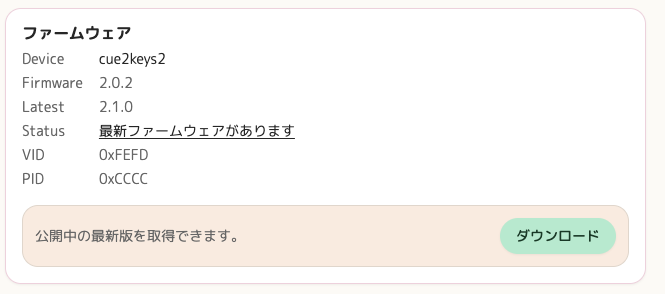
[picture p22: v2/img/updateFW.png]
updateFW


ペンダントの`rst`ボタンは、2回ゆっくりダブルクリックすると書き込み待ち状態になります。ケースはゆっくり左右に揺らしつつ上にスライドすると外せるので、外して押しても良いですし、ケースの穴から細いピンで押しても良いです。
書き込み待ちになると、`rst`ボタン付近のLEDが光ります。
もしうまく書き込み待ちにならない場合は、PCからケーブルを抜き、`bt`ボタンを押しながら接続してしばらく待ってみてください。

PCからストレージとして認識されるので、先ほどダウンロードしたUF2ファイルをドラッグ&ドロップします。しばらく待ってからPCからケーブルを抜き、接続し直してください。

書き込み後は先ほどの手順を繰り返し、動作に問題がないかを確認してください。

### Step2: モジュールの接続確認

次に、ハブモジュール経由でデバイスを接続し、デバイス一覧に出てくるかを確認します。

まずはPCとペンダントの接続を外します。
次に、ペンダントモジュールのチャンネル1にLANケーブルを繋ぎ、もう片方をハブに繋ぎます。



> [!TIP]
> PCと接続中にデバイスを抜いても、残りのデバイスで動作するようになっています。
> また、Webアプリのデバイス一覧から「再読み込み」を押すと、新しく接続されたデバイスを読み込むことができます。
>
> しかし、不安定な状態になることもあります。
> 可能ならPCから接続を外し、デバイスを接続した後繋ぎ直すのがおすすめです。

今回はディスプレイとマグキーが接続されていると仮定しています。チャンネル1の位置的に、左手側に配置したいものを接続するのがおすすめです。

チャンネル1に接続し、ペンダントをPCと繋ぎ、Webアプリから確認すると、次のように表示されます。
ここではハブにキーモジュールが7個、マグネキーモジュールが1個、ディスプレイが1個繋がっている想定です。
モジュールの順番は、現状気にしないで構いません。

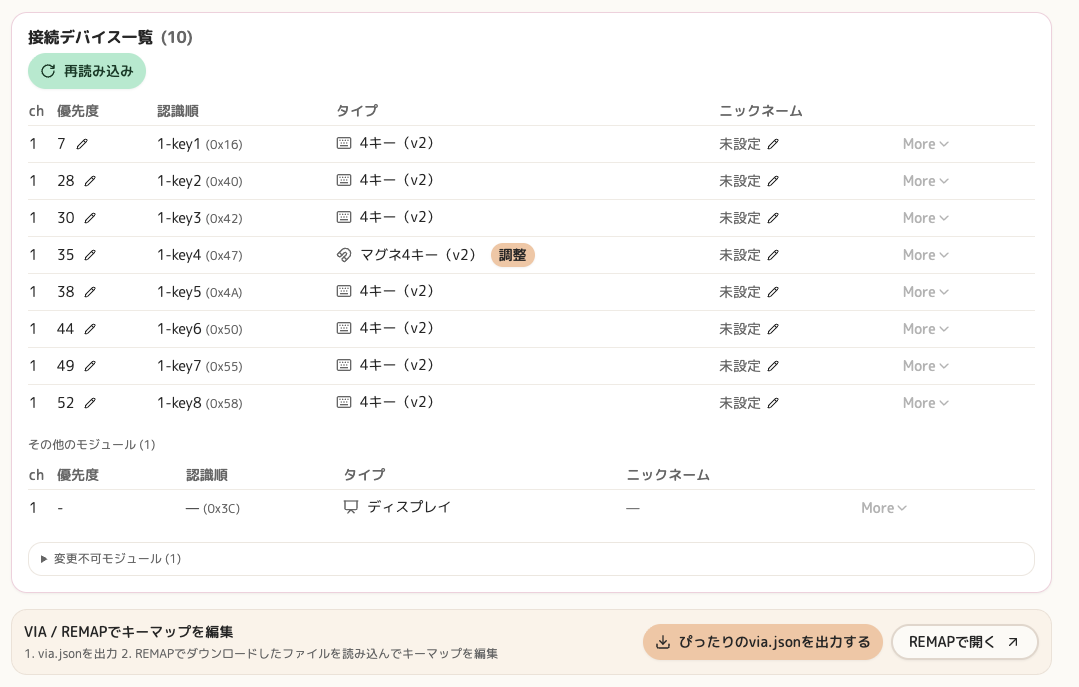
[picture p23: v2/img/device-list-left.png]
device-list-left


またディスプレイにも次のような表示が映ります（接続されているモジュールによって表示は変わります）。

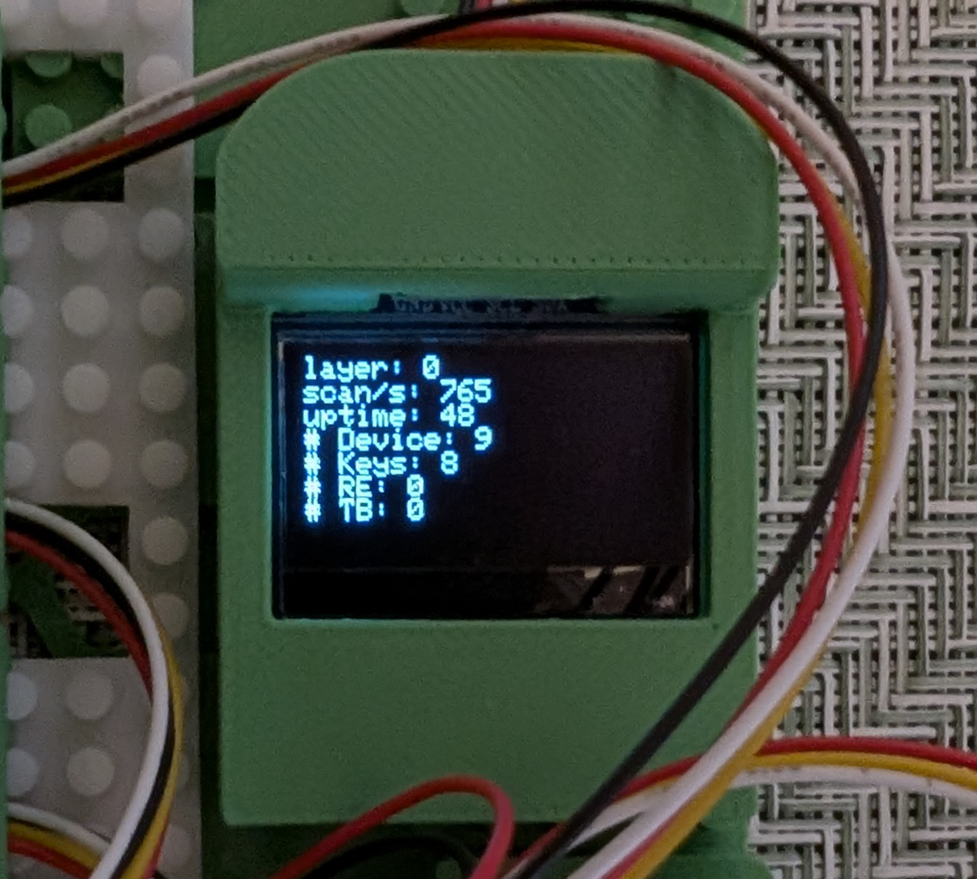
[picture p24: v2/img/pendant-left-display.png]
pendant-left-display


接続されている数と表示が合っていれば次に進んでください。
もし一部モジュールが認識されない場合は、[トラブルシューティングガイド](./troubleshoot.md)に進み、数が一致するまで確認をしてください。

チャンネル1で正常に確認できたら、チャンネル4にも接続をします。
位置的に、右手側に配置したいものを接続します。

pendant-both

トラックボールは、ハブの端にある6pinに接続できます。1つのハブには前後両面に1つずつ接続口がありますが、接続できるのは1つです。

tb-hub

スターターセット DXでは、最終的に次のような表示になれば正しく認識されています。

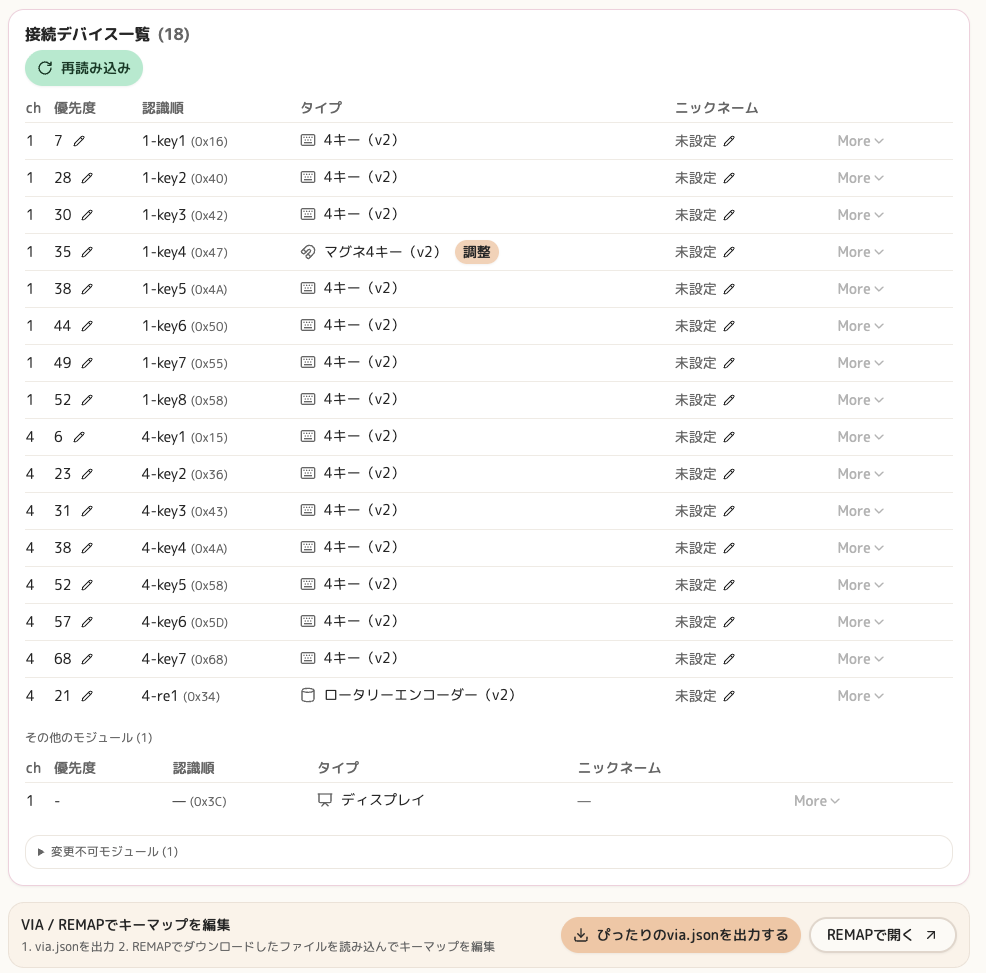
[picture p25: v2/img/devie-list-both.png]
devie-list-both


### Step3: モジュールの特定

モジュールが認識されることを確認したら、初期設定を行います。
接続されているモジュールは、物理的な位置と認識上の位置がバラバラになっており、どれがどのキーに対応するかはわからない状態になっています。
そのため、物理的な配置と合うように順番を設定してあげる必要があります。

まずは、どのモジュールがどう認識されているのかを特定しましょう。
ディスプレイモジュールをつないでいるかで作業の簡単さが変わります。

なお、特定したモジュールには、Webアプリの機能でニックネームを付けるのがおすすめです。
好きな名前で良いですが、分かりやすいように左から`左端`、`Q列`、`W列`、`...`のように、一般的なキーキャップの印字に従って付けるのがおすすめです。
なお、この別名はブラウザ側に保存されているため、別のPCやブラウザを使うとリセットされます。設定でエクスポートもできますので、適宜活用ください。

#### ディスプレイを利用する場合

Webアプリのメニューから「ディスプレイ」を選び、ディスプレイ表示を「入力デバイス表示」[^display-input-name]にします。
これは、最後に入力されたキーやノブの場所とアドレスを表示するものです。

[^display-input-name]: 名前は変更されているかもしれません。適宜読み直してください。

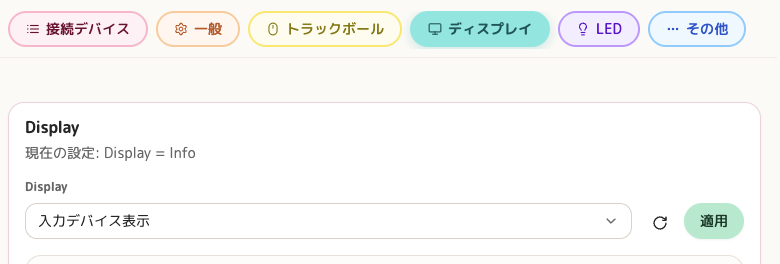
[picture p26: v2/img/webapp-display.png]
webapp-display


適用を押すと、ディスプレイの表示内容が変わります。

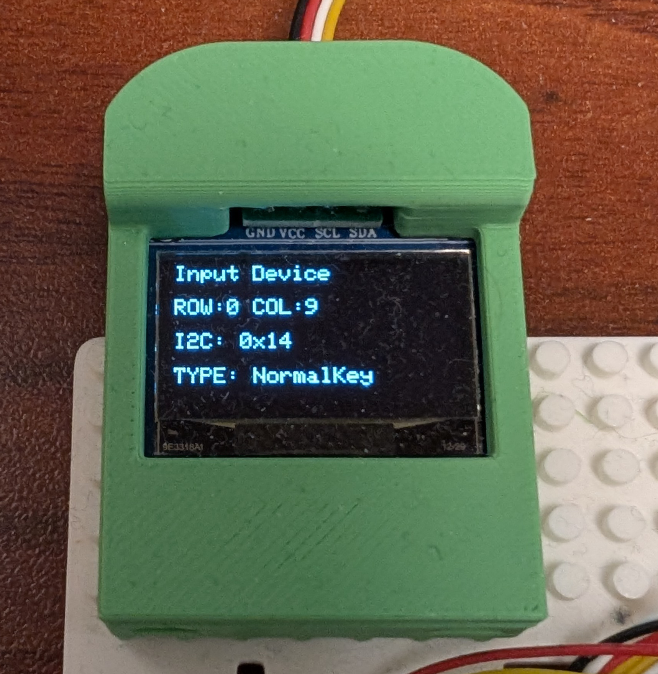
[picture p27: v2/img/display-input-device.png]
display-input-device


この状態で一つだけキーを押して表示が変わることを確認してください。
表示された`I2Cアドレス`とWeb App側のデバイス一覧表示を確認し、一致するものを探して特定します。

#### ディスプレイを利用しない場合

ディスプレイモジュールがない場合は、物理的に一つずつ抜き差しをして特定をします。

スターターセットなどで複数のモジュールがすでにつながっている場合は、一つずつ抜いて、どのアドレスがデバイス一覧から消えたかを記録します。特定できたものは別途メモしておきましょう。

### Step4: モジュールのアドレス設定

無事すべてのモジュールを特定できたらファームウェアから認識する順を変更します。アドレスが小さい順から左に並ぶようにすると分かりやすいです。
アドレスの変更もWebアプリから行います。

> [!IMPORTANT]
> 同じチャンネルで同じアドレスを設定すると、片方が消えたように見えます。
> こうなってしまうとそのままでは設定ができなくなります。
> 
> 競合しているモジュールのどちらかを外して、アドレスを変更した後、つなぎ直してください。

Webアプリのデバイス一覧では、「認識順」をクリックして編集ができます。
1から始まる番号を付けられるので、左端が1になるように変更してみましょう。
すでに1がある場合は一時的にそれを他のアドレスに変えて逃がします。
設定できる数字にはゆとりがあるので、隣接するモジュールでも3つ以上空けて設定するのがおすすめです。

> [!NOTE]
> 負荷が高い処理のため、稀に上手く処理が完了しない場合があります。
> 挙動が怪しい場合、ペンダントをPCから抜いて差し直し、再度確認してください。

物理的な順番と認識順が一致したら、次に進みます。

### Step5: モジュールの物理配置

次に、物理的な配置を整えましょう。

まずはキーキャップを装着します。
その後、土台の好きな位置にキーを移動し配置します。

> [!TIP]
> 土台製造の都合上、ばらつきが生じます。
> 硬くて嵌め込みにくい場合もありますが、完全に差し込めなくても固定できます。
> 使っていくうちに少しずつはめ込みやすくなることもありますので、しばらく様子見いただけますと幸いです。

キーモジュールを密着して配置させる場合、フレキケーブルを適切に折り曲げる必要があります。
あまり上部に伸びすぎるとキーキャップと干渉してしまうので、短くなるよう折り曲げるのがおすすめです。
キーモジュールのケースには切れ込みがあるので、そこを通して調整ください。

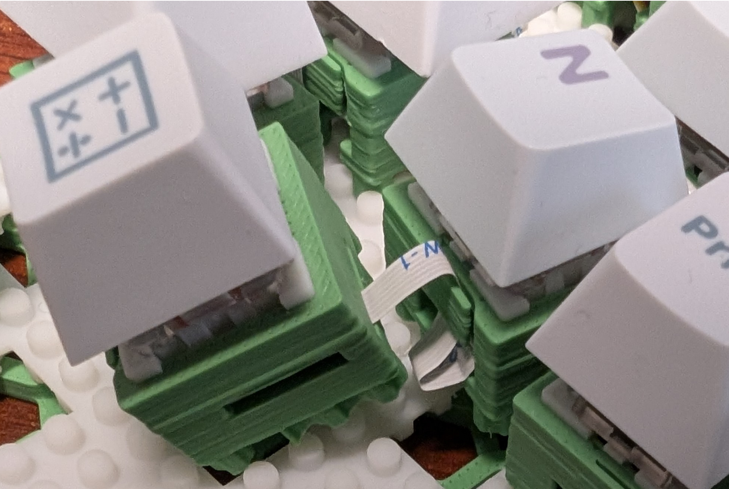
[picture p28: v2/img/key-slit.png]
key-slit


また、先頭キーからは4ピンのケーブルが伸びています。
これはケース底面のスリットを通したうえで、土台に配置をする必要があります。
細いので、土台と挟んで押し込んでしまうと切れてしまう場合もあるのでご注意ください。

4ピンケーブルは、土台の穴から通すことで、きれいにハブに接続ができます。
ただし組み替えは行いにくくなりますので、一旦上方向に伸ばしてハブに接続をし、配置が決まった後後半にあるガイドを参考にしてください。

うまく並べられたら次に進みます。
なお、移動中に力が加わり、ケーブルが接触不良になることがあります。
認識しているデバイス数を確認し、問題があれば[トラブルシューティングガイド](./troubleshoot.md)を参考に修正してください。

### Step6: キーマップの調整

最後にキーマップを変更します。Webアプリの接続デバイス一覧の下に`ぴったりのvia.jsonを出力する`というボタンがあります。
これを押すと、現在の構成に従ってキーマップを変更するためのファイルがダウンロードされます。

実際のキーマップの編集は、[REMAP](https://remap-keys.app)を利用します。VIAに対応しているものであれば他のアプリでも問題ありません。
このガイドでは、使いやすいREMAPで説明します。

キーボードを接続すると次のような画面が出ます。
ここでは、先ほどダウンロードしたvia.jsonを読み込ませます。

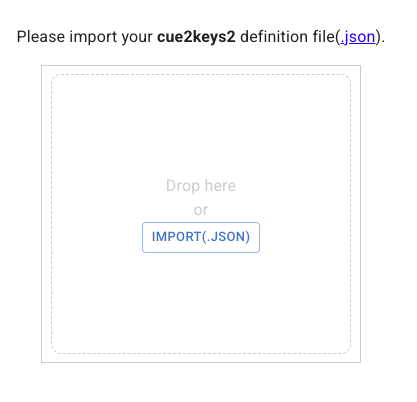
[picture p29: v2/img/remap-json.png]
remap-json


すると次のような画面が出てきます。実際の表示は、接続しているデバイスによって異なります。

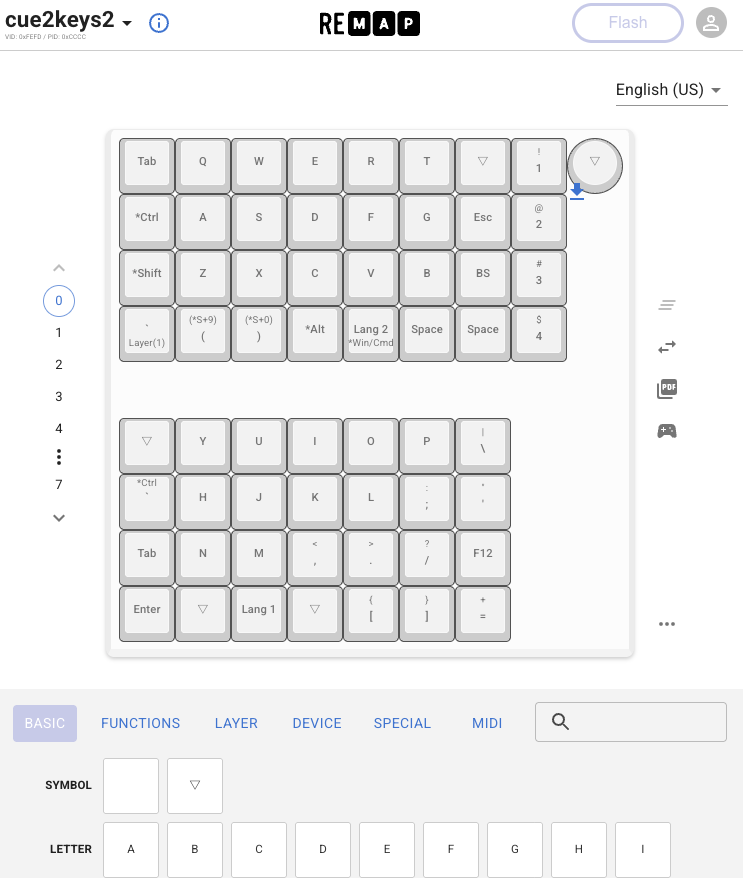
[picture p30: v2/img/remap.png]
remap


初期状態は構成にかかわらず標準のキーマップが設定されていますので、自由にキーマップを編集してください。
対応するキーの設定を変更し、右上のFlashを押すと更新できます。
設定したら実際に叩いて確認をしてみましょう。

ここで設定した内容は、ファームウェアの更新など、いくつかの理由でリセットされることがあります。REMAPには設定したキーマップを保存する機能もありますので、こまめな保存がおすすめです。

### Step7: モジュールの調整

くっつきー2では各種モジュールを細かく調整できます。
Webアプリから設定できるので、いろいろいじって試してみてください。

#### マグネキーの調整

ここでは試しにマグネキーのアクチュエーションポイント、リセットポイント、ラピッドトリガーの設定を変更してみましょう。

マグネキーを接続していると、接続デバイス一覧に調整ボタンが出ます。これをクリックすると、調整のためのフォームが表示されます。

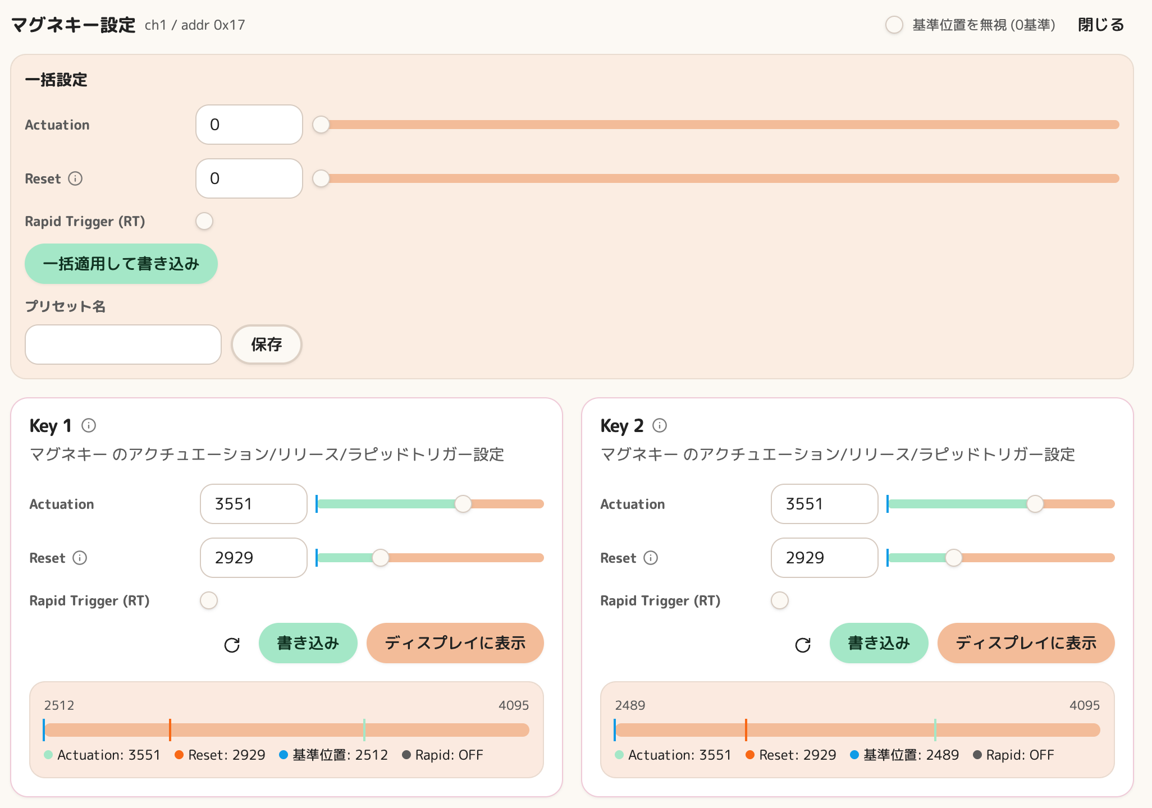
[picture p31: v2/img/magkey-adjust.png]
マグネキーの調整


設定したいキーのカードにある`ディスプレイに表示`ボタンを押してみましょう。
するとディスプレイにそのキーが認識している値が出てきます。スイッチを押し込むとゲージが伸び、離すと戻ります。

ここで数値を確認しながらアクチュエーション、リセットの数値を変更し、書き込みをしてみましょう。
反応するポイントが変わっているはずです。

また、ラピッドトリガーのチェックボックスを入れると、リセットポイント値が意味合いが変わります。
最後に押し込んだ点からどれだけ離すとリセットされるかに変わりますので、こちらも色々な数値で試してみてください。

お気に入りの設定があれば`一括設定`を使って、そのモジュールにまとめて適用することもできます。

> [!NOTE]
> アクチュエーションポイントを`0`など、何もしていない時の数値より小さくしてしまうと、ずっと押し込まれた状態になります。
> 正しい値に修正してつなぎ直しましょう。

#### トラックボールの調整

トラックボールタブでは角度やポインターの移動速度などを設定できます。
こちらはUI通りなので、実際に動かしながら様々な値を試し、自分に合う値を見つけてみてください。

### Step8: 完成！そして調整へ

お疲れ様でした！

組み上がった形で自由にタイピングをしてみましょう。
実際に使ってみると、また調整したい部分が出てくるかと思います。

一通り試せたら、下記のガイドを参考にさらなる調整を試してみましょう。

## 変形のTIPS

一通りの動作確認ができたら、自分の望む形に変更してみましょう。

### まずは微調整から

親指部分のキー配置、縦列を列ごとずらす、オーソリニア配列を作ってみる、といった調整を試してみるのがおすすめです。

キースイッチ、ノブも変更できますので、お好きなものを試してみてください。

### 土台の滑り止め

土台には粒状の滑り止めが付属しています。

土台ケースがある場合は、底面の四隅に貼り付けやすいスペースがありますので、そこに貼り付けるのがおすすめです。
中心に少し高さが出て、しなりが生まれます。
これを嫌う場合は、シート上の滑り止めを別途用意し、中央に配置すると吸収できます。
もちろん、お気に入りの滑り止めがある場合は、付属のものを使わなくても問題ありません。

### ロウスタッガードの注意点

ロウスタッカード配置は、カラムスタッカードに比べ難易度が高い配置です。
ケーブルの柔軟性を使い、横並びと縦並びを組み合わせて目的の形を作ってみましょう。

また、キーのリマップも見た目と異なる形になります。慣れるまではややこしいので、カラムスタッガードで十分慣れてから操作をするのがおすすめです。

### キー数を減らす

配置によってはキー数が過剰になる場合があります。
その時は[キーモジュール詳細](./modules/keys.md)のページに従い、キー数を減らすことができます。

## ケーブル整理

ケーブル部分を整理する方法をまとめます。
形が変更しにくくなりますので、配置がある程度定まってから取り組むのがおすすめです。

### ケーブルの地下配置

ケーブルは土台と外ケースの間にある隙間を通すことができます。これにより、ケーブルが表に出ず、すっきり整理することができます。

まずは土台と外ケースを分離します。ゆっくりと四隅を押し出すように、少しずつ力を加えて外します。

外ケースの土台との接触部は、縦横にへこんでいるケーブルトンネルがあります。各モジュールは土台の穴を経由してこのトンネルを伝い、ハブに伸ばすことになります。

土台にモジュールを配置し、底面のスリットを通したりして、4pinケーブルを土台の穴から下に通します。
その後、うまく外ケースの凹みに合うようにケーブルを押さえつけます。マスキングテープなどで固定するのも良いでしょう。

その後、外ケースを取り付け直し、モジュールをハブに接続します。
移動中にケーブルが接触不良になることもありますので、動作確認をし、問題があればトラブルシューティングガイドを参考に修正してください。

### ハブケースの穴

ケーブルは、長さが余ってしまうと外に広がってしまいます。
その場合、ハブケースにある穴を使って整理することができます。

例えば、隣の穴と一周させて長さを消費したり、穴を通して反対側のコネクタに接続することで長さを調整できます。

構成に合わせてうまく設定してみましょう。

### 土台ケースのケーブル固定スリット

ハブを配置する箇所の手前に細いスリットが入った箇所があります。
ここにはケーブルを通して固定することができます。

一時的な作業のために固定するのも良いですし、長さが余っている場合、ここを使うことでケーブルが跳ね上がらないようにすることもできます。

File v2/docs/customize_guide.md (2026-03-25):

# カスタマイズガイド

くっつきーシリーズは様々なカスタマイズが可能です。ここでは、難易度別にカスタマイズ方法を紹介します。
自分の技術レベルや目的に合わせて、好みのカスタマイズを楽しんでください。

## 簡単なカスタマイズ

特別な知識やツールが必要なく、誰でも簡単に試せるカスタマイズです。

### パラメーターを変える

くっつきー2では、ブラウザから操作できるWebアプリでトラックボールの角度やマグネキーのアクチュエーションポイントなど、様々な設定を変更できます。
ぜひアクセスして確認してみてください。

https://app-cue2keys.esplo.net

### キーキャップを変更する
- 打鍵感や見た目を自分好みに変えられます
- Cherry MX互換のキーキャップであれば使用可能です
- 特にロウスタッガード配列の場合は、キーキャップの互換性を事前に確認してください

### キースイッチを変更する
- 打鍵感に大きく影響する重要な部分です
- リニア、タクタイル、クリッキーなど、様々なタイプから好みのスイッチを選べます
- キーモジュールのスイッチは、工具なしでも手で取り外し可能です

### ノブを変更する
- ロータリーエンコーダーのノブ部分は交換可能です
- 様々な形状や素材のノブが市販されています
- 固定が硬い場合があります。十分に注意して外してください。ドライバーなどを使ってテコの原理で力を加えると外しやすいです

### 滑り止めを追加・変更する
- 使用状況に合わせて滑り止めを追加できます
- 100円ショップなどで入手できるシリコンパッドやゴム足などが使えます
- キーボードの安定性や打鍵時の振動吸収に効果的です

### キーマップをカスタマイズする
- [キーマップガイド](./keymap_guide.md)を参考に、自分の使い方に最適化しましょう
- 頻繁に使うキーを押しやすい位置に配置したり、マクロを設定したりできます
- 複数のレイヤーを活用することで、限られたキー数でも多機能な設定が可能です

## 専門知識が必要なカスタマイズ

プログラミングや3Dプリンティングなどの専門知識が必要なカスタマイズです。

### ファームウェアをカスタマイズする
- [ファームウェアガイド](./firmware_guide.md)を参考に、自分だけの機能を追加できます
- カスタムキーコードの追加やディスプレイの表示内容変更などが可能です
- QMKの知識が必要ですが、既存のコードをベースに修正することで比較的取り組みやすいでしょう

### ケースや土台を3Dプリントする
- 3Dプリンタがあれば、各モジュールのケースを自分で印刷できます
- STLデータは[3Dフォルダ](../3D/)で公開しています
- 好きな色や素材で印刷することで、完全にオリジナルのキーボードが作れます
- 破損したケースの修理・代替品としても活用できます

## 改造

完全にオリジナルの機能やモジュールを作る本格的な改造です。
もし必要なモジュールが無い場合は、まず[issue](https://github.com/esplo/cue2keys_resources/issues)に要望を投稿してみてください。
同じニーズを持つ仲間が見つかったり、公式での対応が検討される可能性もあります。

### オリジナルケースや土台の設計・製作
- 自分だけの特殊なレイアウトやデザインのケースを作成できます
- 3DCADの知識が必要ですが、既存のデータを参考にアレンジすることも可能です

### オリジナルモジュールの開発
- 基板設計から取り組む必要がありますが、7キーモジュールやL字型キーモジュールなど、独自の機能を持つモジュールを作ることができます
- 電子工学の知識と実装スキルが必要です

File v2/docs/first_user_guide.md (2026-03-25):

# 初代ユーザー向けガイド

初代くっつきーをご購入いただいた方のためのガイドです。

## 初代ユーザー特典

ご愛顧に感謝し、初代ユーザー特典を実施します。

- 期間: くっつきー2リリースから約半年間（3/28-9/29）
- 条件: 初代ペンダントの基板表裏の提示
- 対象製品: くっつきー2 スターターセット、各種モジュール。初代ユーザー向けモジュール（アップグレードキット）は既に値引きが入っているため対象外

イベントなど対面での購入では、初代ペンダント実物（または基板両面の写真）をお持ちいただくと10%の割引で購入いただけます。

boothでの購入の場合、購入直後にメッセージ機能で初代ペンダント基板表裏の写真をお送りください。購入価格の約10%のおまけを付けて送付します。

## アップグレード

初代のモジュールを活かしつつ、くっつきー2にアップグレードすることができます。
特に、2で新しく登場したマグネキーモジュールや25mmトラックボールを混在させたい場合に有用です。

ただし、くっつきー2ではケーブルの形状および処理方法を変更しており、初代くっつきーにくっつきー2のモジュールは利用できません。
また、くっつきー2から初代モジュールを使うためには変換モジュールが必要です。

1. くっつきー2の接続モジュールを揃える
   - ペンダントx1、ハブは必要数（両手分なので通常2つ）
2. 変換モジュールをハブの数だけ揃える
3. ビルドガイドに従い接続

変換モジュールは、初代ケーブルの4pin/6pinが接続できる側、くっつきー2の4pin/6pinケーブルが接続できる側があります。

初代側では4pinケーブルでハブと接続し、6pinケーブルで初代トラックボールを接続します。
2側では、4pinケーブルと6pinケーブルをハブに接続します。
この機、初代トラックボールを接続しない場合は、6pinケーブルを繋ぐ必要はありません。

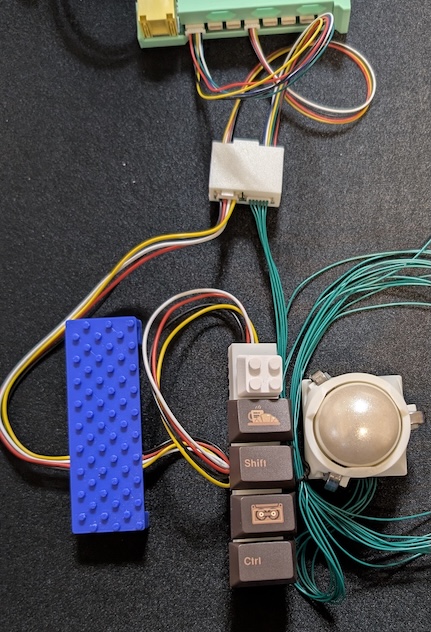
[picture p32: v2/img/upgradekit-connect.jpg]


中央の白い箱で示されるのが変換モジュールです。
接続した先のくっつきー2のハブでは、2のモジュールが利用できます。

変換モジュールには必要なケーブルが付属します。

- 初代4pinケーブル
- 2の4pinケーブル
- 2の6pinケーブル

### アップグレードキット

初代スターターセットをお持ちの方に向けて、必要なモジュールをセットにしたお得なキットを販売します。

- ペンダント
- ハブx2
- 変換モジュールx2
- ディスプレイ

くっつきー2ではペンダントとディスプレイが分離しているので、ディスプレイモジュールも付けています。
このキットに加え、使いたいくっつきー2のモジュールをお求めいただくことでスムーズに移行できます。

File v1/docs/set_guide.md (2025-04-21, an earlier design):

# セット購入者の方へ

くっつきーをご購入いただき、ありがとうございます。
このページでは、組み立て済みのセット商品をご購入された方向けの情報を掲載しています。

本ガイドは2025年4月以降の製品を対象としています。
内容は状況に応じて変更される場合がありますので、あらかじめご了承ください。

## 内容物の確認

まずは必要な内容物がすべて揃っているか、破損がないかを確認してください。
不足や破損がある場合は、[X（旧Twitter）](https://x.com/cue2keys)のDM、BOOTHの購入者メッセージなどでご連絡ください。

### スターターセット

スターターセットは、あらかじめ組み立てた状態で梱包されています。

セット内容：
- ペンダント：1個
- 5キーモジュール：10個
- 4キーモジュール：4個
- 土台：2個
- ハブ：2個
- 10°チップ：8個
- 水平チップ：4個
- 滑り止め：8粒

付属ケーブルの合計数（参考）：
- 4ピンケーブル：14本
- USBケーブル：3本

### スターターセット DX

スターターセット DXは、通常のスターターセットに加えて、以下のモジュールが追加されています：

追加モジュール：
- トラックボール：1個
- ノブ（ロータリーエンコーダー）：1個

追加ケーブルの合計数（参考）：
- 4ピンケーブル：1本
- 6ピンケーブル：1本

### クリエイター用マクロパッド

セット内容：
- ペンダント：1個
- 5キーモジュール：3個
- 4キーモジュール：1個
- ノブ（ロータリーエンコーダー）：3個
- 土台：1個
- ハブ：1個
- 10°チップ： 4個
- 水平チップ：2個
- 滑り止め：4粒

## 初期設定と使用方法

セット製品は、基本的な組み立ては完了しています。ここからの手順については、[ビルドガイド](./build_guide.md)の「6. 接続の確認」以降を参照してください。

主な手順：
1. PCとの接続
2. 動作確認（ディスプレイの表示確認）
3. キーマップの設定
4. 必要に応じた調整（トラックボールの角度、速度など）

よくある質問については[FAQ](./faq.md)もご確認ください。

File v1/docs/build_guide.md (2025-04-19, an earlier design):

# ビルドガイド

このページは、[くっつきー](https://cue2keys.esplo.net/)のビルドガイドです。
質問や要望は[issue](https://github.com/esplo/cue2keys_resources/issues)にお寄せください。

## 概要

ロゴ

くっつきーは、フルモジュラー方式のキーボードです。
キー、トラックボール、ロータリーエンコーダーなどのモジュールを自由に接続し、お好みの機能を持ったキーボードを構成できます。

詳細は[公式サイト](https://cue2keys.esplo.net/)をご覧ください。

## 用意するもの

- クリップなどの細いピン
  - 本体のスイッチを押すために使います
- Cherry MX互換のキーキャップ
  - 構成に合わせた数を用意します
  - キーモジュールが横向きになる場合は、キースイッチとキーキャップの相性が問題ないか事前に確認してください
- （あると嬉しい）パームレスト

## 組み立て手順

※ スターターセットなど構成済みセットを購入された方は、手順6から開始できます。まずは[セットガイド](./set_guide.md)をご覧ください。

### 1. 作りたいキーボードを考える

[公式サイト](https://cue2keys.esplo.net/)の構成例などを参考に、自分が理想とするキーボードの構成を考えましょう。

### 2. 必要なモジュールを揃える / 購入ガイド

モジュールは[BOOTH](https://c2k.booth.pm)やイベントで販売しています。
考えた構成に必要なモジュールを揃えましょう。

ただし、モジュールごとに制限がありますので、購入前に確認してください。
不明な点は[issue](https://github.com/esplo/cue2keys_resources/issues)や[SNS](https://linktr.ee/cue2keys)でお問い合わせください。

現時点での接続方式や制限は以下の通りです：

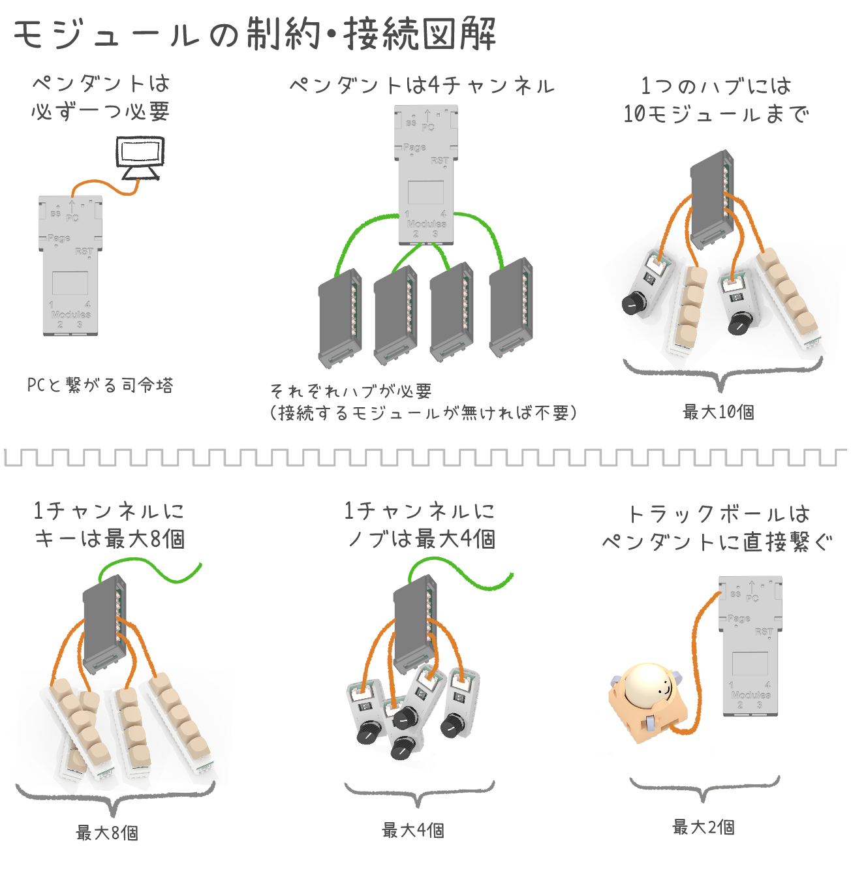
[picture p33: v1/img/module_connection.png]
モジュール接続解説画像


- PCと接続するモジュールである「ペンダント」は、必ず1つ必要です
- ペンダントは4つのチャンネル（接続口）を持っています
- 使用する1チャンネルにつき1つのハブが必要です（そのチャンネルに何も接続しない場合は接続不要）
- 4キーと5キーモジュールは、1チャンネルにつき合計で8つまで接続できます
  - 8つ以上接続する場合は、他のチャンネルに分散させてください
- ロータリーエンコーダーは1チャンネルにつき4つまで接続できます
- トラックボールは特殊なモジュールです。最大2台まで接続可能でハブは不要です

スターターセットを例に見てみましょう：

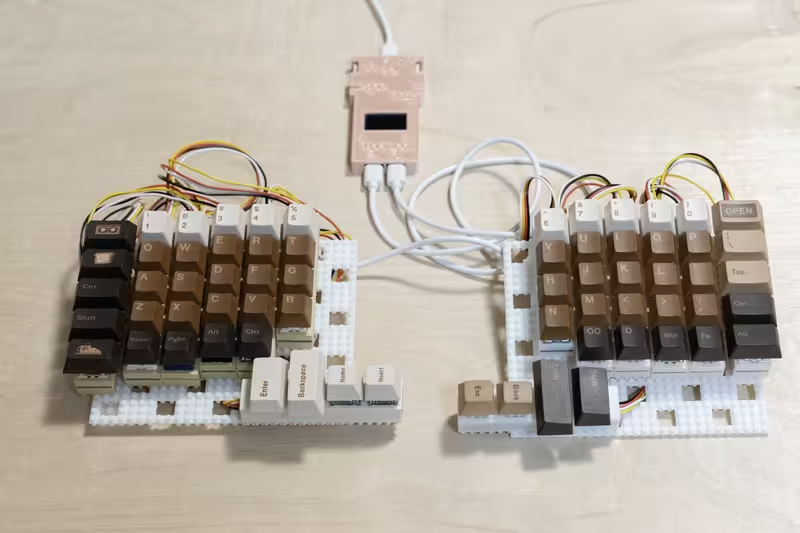
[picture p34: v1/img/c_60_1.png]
スターターセットの画像


スターターセットは左右分割、66キーのキーボードです。
左手部分は5キーモジュールが5つ、4キーモジュールが2つで構成されており、ハブ経由でチャンネル1に接続しています。
キーモジュールは合計で7つなので、上限の8個を超えていません。
右手も同様の構成で、こちらはチャンネル2に接続しています。

### 3. 配置を考える

土台に各モジュールを仮置きして、配置を決めます。
この段階ではまだしっかりと固定せず、簡単に取り外せる状態にしておきましょう。

キーの配置だけでなく、トラックボールやロータリーエンコーダーをどこに配置するか、傾斜をどうするかも考慮します。
スターターセットでは、ハブは土台の下に置き、ハブと土台の間に10°チップを設置するのが標準的な方法です。

なお、ロウスタッガード（行をずらした配列）の場合は、キースイッチが横向きになるためキーキャップがはまりにくい場合があります。キースイッチとキーキャップの互換性を事前に確認してください。

配置が決まったら、次はモジュールの設定を行います。

### 4. モジュールのアドレス設定

キーモジュールとロータリーエンコーダーは、ディップスイッチでアドレスを指定する必要があります。
この設定は**キーマップと連動**するため、スターターキットなど既定のキーマップがある場合は特定の設定にする必要があります。

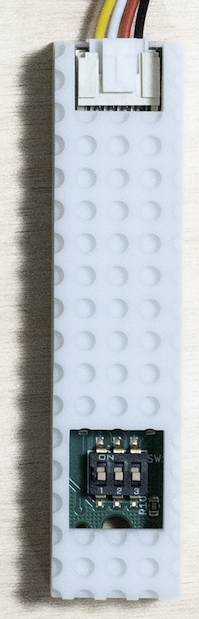
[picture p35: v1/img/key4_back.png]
key4の背面


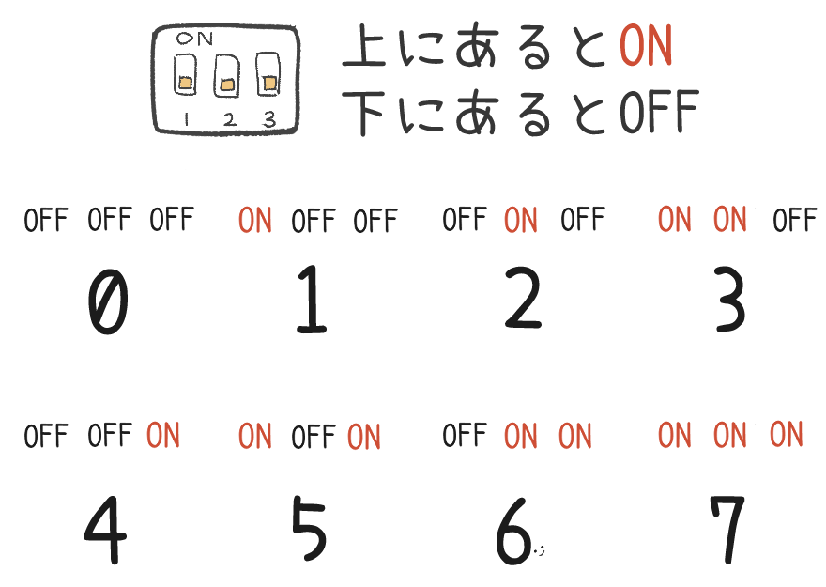
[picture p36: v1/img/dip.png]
DIPスイッチ対応表


同じチャンネル内では、同一タイプのモジュールに**重複したアドレスを設定しないでください**。
キーモジュールとロータリーエンコーダーは独立しているため、同じ設定でも問題ありません。
分かりやすくするために、左側から0, 1, 2...と順番に設定するのがおすすめです。

- キーモジュール
  - 3つのスイッチがあり、8通り（0〜7）の設定ができます
- ノブ（ロータリーエンコーダー）
  - 2つのスイッチがあり、4通り（0〜3）の設定ができます
  - 3つ目のスイッチはケースで隠れていますが、必ずOFF状態にしておく必要があります。もしONになっている場合は、OFFに変更してください

### 5. 接続する

設定が完了したら、ケーブルで各モジュールを接続します。
モジュールによって異なるケーブルと接続先がありますので、以下を参考にしてください。

モジュール接続解説画像

- キーモジュール・ロータリーエンコーダー
  - ハブに接続します（4本線のHYケーブルを使用）
  - ハブには左右に各5個、計10個のソケットがありますので、好きな場所に接続できます
  - キーモジュールとロータリーエンコーダーの合計が10個を超える場合、1つのハブでは足りません。ハブを連結することも可能ですが、別のチャンネルのハブに分散することをおすすめします
- トラックボール
  - ペンダントに直接接続します（6本線のZHケーブルを使用）
  - 最大2個まで接続可能です
- ハブ
  - ペンダントに接続します（USB A-Cケーブルを使用）
  - ペンダントの下部にある4つのチャンネルのいずれかに接続します
  - 接続するチャンネルによってキーマップとの対応関係が変わります。通常はチャンネル1から使用することをおすすめします
  - 標準のケーブル長は1.5mですが、必要に応じて延長することも可能です（ただし、長すぎると誤動作の原因となる場合があります）

すべて接続できたら、最後にペンダントとPCを接続します。接続にはUSB C-AまたはC-Cケーブルが使用できます。ケーブルの長さが足りない場合は、延長ケーブルを使用することも可能です。

なお、接続に必要な各種ケーブルはモジュール購入時に付属しています。
長さなどを変更したい場合は、各モジュールの詳細ページに記載されているケーブル仕様を確認して、適切な代替品を探してください。

### 6. 接続の確認

PCと接続してキーを押すと、ペンダントのディスプレイに情報が表示されます。
表示されない場合は、ファームウェアが正常に書き込まれていない可能性があります。
その場合は[ファームウェアガイド](./firmware_guide.md)を参照して、ファームウェアを書き込んでください。
問題が解決しない場合は、接続の確認や他のモジュールを一時的に外して接続テストを行ったり、FAQを確認してください。

ディスプレイ（1ページ目）には、接続されているモジュールの種類と数が表示されます：

- `# Devices`: トラックボール以外の認識されているモジュール数
- `KEY4`: key4モジュールの認識数
- `KEY5`: key5モジュールの認識数
- `RE`: ロータリーエンコーダーモジュールの認識数
- `TB`: トラックボールモジュールの認識数

表示されている数が実際の接続数と異なる場合は、同一チャンネル内で重複したアドレスが設定されている可能性があります。
また、ケーブルがしっかり接続されているか、ケーブル自体に問題がないかも確認してください。

### 7. キーマップの設定

接続が正常に完了したら、次はキーマップを設定します。
詳細な手順については[キーマップガイド](./keymap_guide.md)を参照してください。

なお、レイヤー3は「マウスレイヤー」として設定されており、トラックボールを操作している間とその後しばらくの間だけ有効になるレイヤーです。
このレイヤーにマウスの左右クリックやスクロール機能を割り当てておくと便利です。

### 8. 調整する

実際に使用してみて、配置やキーマップを調整しましょう。
キーの配置を大きく変更する場合は、手順3からやり直すと良いでしょう。

トラックボールについては、ソフトウェア側で角度、速度、マウスレイヤーの設定など、様々な調整が可能です。
詳しくは[カスタムキーコード一覧](./custom_keycodes.md)を参照してください。

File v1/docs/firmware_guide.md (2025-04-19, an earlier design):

# ファームウェアガイド

このページでは、くっつきーのファームウェア（デバイスを制御するソフトウェア）に関する解説を行います。

キーボードとしての機能は、ペンダントモジュールに書き込まれたファームウェアによって実現しています。
挙動を変更したいときや動作に問題があるときは、ファームウェアを更新することで解決できる場合があります。

## 現行ファームウェア

ビルド済み（すぐに使える状態）のファームウェアは以下のリンクからダウンロードできます。
通常のユーザーは、こちらをダウンロードして[ファームウェアの書き込み方法](#ファームウェアの書き込み方法)を参照してください。

[ビルド済みファームウェア](../firmware/cue2keys_latest.uf2)

ソースコードは[esplo/cue2keys_firmwareのvia-enabledブランチ](https://github.com/esplo/cue2keys_firmware/tree/via-enabled)で公開しています。プログラミングの知識がある方は、フォークして自由に変更することもできます。

なお、現在書き込まれているファームウェアのバージョンは、ディスプレイの最後のページに表示されます。

### 主な機能

- QMK/VIAによるキーリマップ対応
  - キーボードの配列を自由に変更できます
- 8レイヤーに対応
  - 複数の機能を切り替えて使用できます
  - 必要に応じてさらに増やすことも可能です
- ディスプレイへの情報表示
  - ペンダントのボタンか、カスタムキーコード（`NEXT_OLED_PAGE`）を押すことでページが切り替わります

### トラックボール関連機能

- トラックボールの自動スリープ機能
  - デフォルトでは5分間使用しないと消灯します
  - キーを押したり、ロータリーエンコーダーを回すと再び点灯し、反応するようになります
- トラックボール使用中のマウスレイヤー自動切替機能
  - トラックボールを動かしている間、マウスレイヤーが自動的に有効になります
  - デフォルトのキーマップでは、レイヤー3がマウスレイヤーとして設定されており、左右クリックなどが割り当てられています

### カスタムキーコード

カスタムキーコード（特殊な機能を持つキー）についての詳細は[カスタムキーコードの説明](./custom_keycodes.md)で確認できます。

主な機能は以下の通りです：

- トラックボールの角度調整
  - 左右それぞれのトラックボールの角度を1°単位または30°単位で調整可能
- 自動マウスレイヤーのオフ遅延時間調整
  - トラックボールを止めてから自動マウスレイヤーが無効になるまでの時間を調整できます
  - 100ms（ミリ秒）単位で調整可能（デフォルトは1300ms）
- トラックボールの移動速度調整
  - 0.25倍単位で調整可能（デフォルトは1.0倍）
- ドラッグスクロール機能
  - 特定のキーを押している間、トラックボールの動きがスクロール操作になります
  - スクロール速度や方向も調整可能
- トラックボールLEDの消灯タイムアウト設定
  - 「なし」「5分」「10分」「15分」から選択可能（デフォルトは5分）
- ロータリーエンコーダーの解像度調整
  - 各エンコーダーの感度を調整可能

## ファームウェアの書き込み方法

ペンダントモジュールにファームウェアを書き込むには、まずブートローダー（初期起動プログラム）を起動する必要があります。
ブートローダーモードでは、キーを入力しても反応しなくなりますので注意してください。
書き込み作業時は、別のキーボードを接続するか、ノートPCの内蔵キーボードでの操作をおすすめします。

ブートローダーを起動する方法はいくつかあります：

- **（おすすめ）ペンダントのRSTボタンをダブルクリックする**
  - ゆっくりと2回押します（クリップなど細いピンで押すことができます）
- PCと接続しているケーブルを抜き、ペンダントのBSボタンを押しながら接続する
- `QK_BOOT`キーをキーマップに割り当てておき、それを押す
  - 頻繁にファームウェアを更新する場合におすすめです

ブートローダーモードになると、PCからは`RPI_RP2`という名前の外部ストレージとして認識されます。
そこに先ほどダウンロードしたファームウェア（`.uf2`拡張子のファイル）をコピー＆ペーストするだけで書き込みが行われます。
書き込み中は、ペンダント右上のLEDが点滅します。

書き込みが完了すると、自動的に接続が解除され、再接続されます。
通常は書き込みから約10秒程度で自動的に再認識（再接続）されますが、うまく認識されない場合は、PCとの接続ケーブルを抜き差しして手動でリセットしてください。

## コードからビルド（上級者向け）

上記に記載の通り、ソースコードは公開されています。
プログラミングの知識がある方は、既存のコードを元に自分だけの機能を追加してみることも可能です。

QMKファームウェアの詳細な解説は、スペースの都合上ここでは省略します。
他のQMKファームウェアと同様の方法で開発を行ってください。

## 設定値をリセットする

**⚠️ 注意**: リセットを行うとREMAPでの設定もクリアされます。キーマッピングを保存したい場合は、REMAPにログインして保存してからこの手順を行ってください。
ファームウェアの更新内容によっては、REMAPの設定が引き継げない場合もあります。あらかじめご了承ください。

カスタムキーコードによる設定（ディスプレイの2ページ目以降で確認できる値）は、ペンダントモジュール内のEEPROM（不揮発性メモリ）に保存されています。
ファームウェアの大幅な更新時には、これをクリアして再設定する必要がある場合があります。

[キーマップガイド](./keymap_guide.md)に従い、`DEVICE`タブにある`KEYBOARD`カテゴリから、`Clear EEPROM`というキーコードをいずれかのキーに割り当ててください。
スターターセットの初期設定では、以下の操作でこの機能を実行できるようにマッピングされています：
1. 左手側の左下のキーを押す
2. その右隣のキーを押す
3. 左上から2つ目のキー（レイヤー2のTab）を押す

リセット後は設定が初期値に戻りますので、必要な設定を改めて行ってください。

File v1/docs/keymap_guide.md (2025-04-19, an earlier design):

# キーマップガイド

くっつきーのキーマップは[VIA](https://caniusevia.com/)という仕組みを使用しており、簡単かつ動的に設定を変更できます。
[REMAP](https://remap-keys.app/configure)などのブラウザベースのツールを使うと、特別なソフトウェアをインストールせずに好みのキーマップを設定できます。
このガイドでは、REMAPを使ったキーマップ設定方法を紹介します。

設定に必要なキーマップ定義ファイルは以下のリンクからダウンロードできます：

[via.json](../firmware/via.json)

## REMAPの使い方

### 準備

1. まずブラウザで[REMAP](https://remap-keys.app/)のウェブサイトを開きます
2. トップページの「キーボードをカスタマイズ」ボタンをクリックします

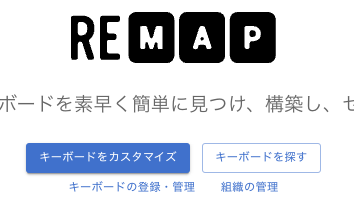
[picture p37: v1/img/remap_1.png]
remap_1


3. くっつきーがPCに接続されていることを確認し、画面上部の「+ キーボード」ボタンを押します

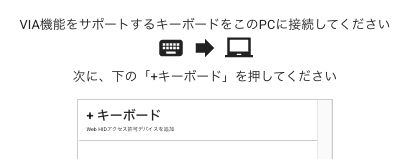
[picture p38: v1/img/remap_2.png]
remap_2


4. ブラウザに接続確認画面が表示されます。リストから「cue2keys」を選択して「Connect」をクリックします

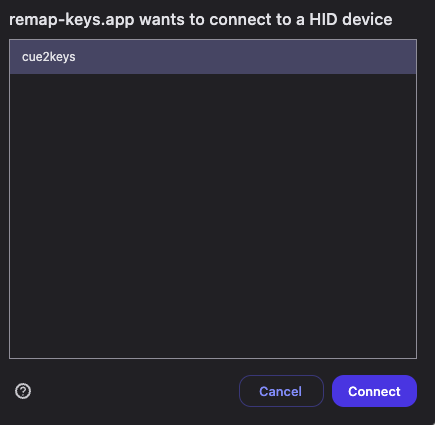
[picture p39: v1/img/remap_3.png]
remap_3


5. 定義ファイルの選択を求められるので、先ほどダウンロードした[via.json](../firmware/via.json)ファイルを選択します

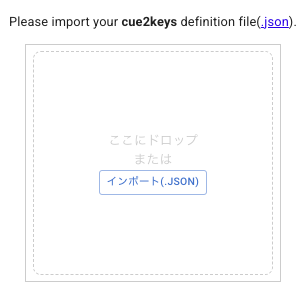
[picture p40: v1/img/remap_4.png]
remap_4


※ 読み込みに時間がかかる場合があります。読み込みが完了しない場合は、ブラウザをリロードして再試行すると解決することもあります。

読み込みが完了すると、接続されている全てのキーが表示された状態になります。

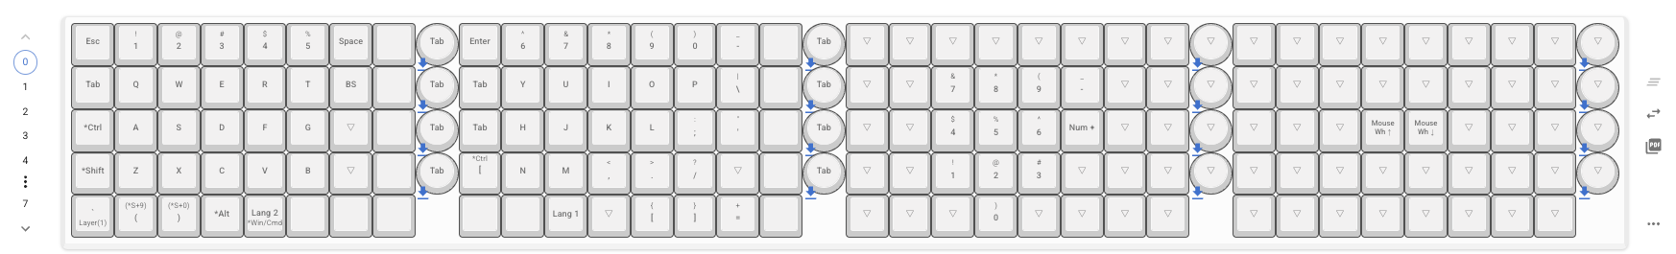
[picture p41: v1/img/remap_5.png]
remap_5


### キーマップの編集方法

キーの設定を変更する方法は非常に簡単です：

1. 変更したいキーのアイコンをクリックします
2. 表示されるメニューから割り当てたい機能やキーを選択します

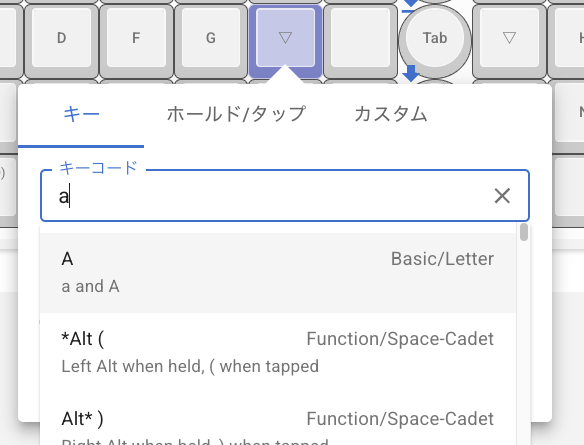
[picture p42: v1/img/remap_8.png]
remap_8


画面左に表示されているレイヤーを切り替えることで、異なるレイヤーのキーマップも設定できます。
通常はレイヤー0で、レイヤー3はトラックボールを動かした際に自動で有効になるレイヤー、他は押したキーや状態によって有効になるレイヤーです。

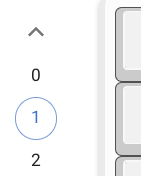
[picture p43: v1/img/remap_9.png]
remap_9


### キーの位置確認方法

どのキーがどの位置に対応しているかを確認するには、テストマトリクスモードの機能が便利です。
接続しているチャンネルやディップスイッチの設定によってキーの位置が変わる場合があるため、設定前に実際のキーの位置を確認することをおすすめします。

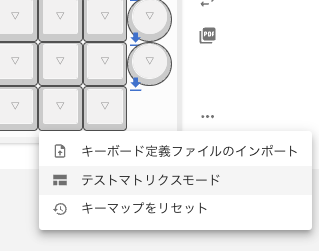
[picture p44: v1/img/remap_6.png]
remap_6


### カスタムキーコードの設定

くっつきー独自の特殊な機能を持つキーコードも設定することができます。
これらの機能は「FUNCTIONS」タブの「VIA USER KEY」カテゴリにあります。
これらのキーを押すことで、トラックボールの角度調整やスピード設定など、様々な調整が可能になります。

詳細な機能リストは[カスタムキーコード一覧](./custom_keycodes.md)をご覧ください。

⚠️ 後半のカスタムキーコードはGUIで表示されませんので、キーコードを入力して指定してください。

remap_7

現在の設定値は、ペンダントのディスプレイ2ページ目以降で確認できます。

## キーマッピングの保存

REMAPにはアカウントを作成すると設定したキーマップを保存できる便利な機能があります。
ある程度設定が固まったら、アカウントを作成して保存しておくことをおすすめします。
次回設定を変更する際や、ファームウェアを更新した後に再設定する際に役立ちます。

## 備考

スターターキットには、最初から一般的なキーマップが設定されています。
しかし、自分の好みや使い方に合わせて自由に変更することができますので、快適に使えるよう調整してみてください。

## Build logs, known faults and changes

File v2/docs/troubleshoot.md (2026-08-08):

# トラブルシューティングガイド

ここに記載のないトラブルが発生した場合は、お気軽にご連絡ください。追記していきます。

## モジュールを認識しない

適宜ペンダントをPCから外し、再度接続してみてください。

まず、問題が起きているモジュールを特定するため、モジュールを着脱して`問題が起こる最小の組み合わせ`を作りましょう。
数が多い場合は後回しでも良いですが、困ったら原因を絞り込むために着脱して確認してみましょう。

### 4pinケーブルの確認

4pinケーブルの接続が外れかかっている場合が多いです。

特にキーモジュールは移動中に引っ張られて抜けてしまうことがあります。
1番目のキーをひっくり返し、後ろにある隙間からマイナスドライバーなどで4pinケーブルをコネクタ側に押し込んでください。
左右両方を少しずつ押し込むとしっかり挿せます。
その後、再度接続して確認してみてください。

### チャンネル（ハブ）の変更

同一チャンネルで同じアドレスを使用していると認識されなくなります。
別のハブにモジュールをつなぐ、または他のモジュールを外すなどして認識されるか確認してみてください。

### チャンネル0に繋いで確認

ペンダントのLED付近には4pin接続コネクタがあります。
これは特別なコネクタで、チャンネル0として扱われます。ここに接続したモジュールは操作はできませんが、アドレスの変更などが行え、他のチャンネルより優先的に認識されます。

ここに接続し、Webアプリの`その他`からチャンネル0のモジュールのアドレスを適当なものに更新してみてください。
その後、ハブに接続し、モジュールが認識されるか確認してみてください。

### 分解して確認

キーモジュールの場合は、キー間を接続しているFPCケーブルの接触も原因として考えられます。
[キーモジュールのガイド](./modules/keys.md)を参考に、分解して再度接続し確認してみてください。

## デバッグ用ファームウェアを利用した調査

[ファームウェアガイド](./firmware_guide.md)の書き込み方法を参考に、デバッグファームウェアを書き込んでください。
デバッグフ用ァームウェアは[ファームウェアリポジトリ](https://github.com/cue2keys/v2_qmk_fw/releases)の`Assets`の中で、名前の末尾が`_debug.uf2`のものです。

デバッグ用ファームウェアは、USBで接続しているPCにログを表示します。
[QMK Toolbox](https://qmk.fm/toolbox)の`HID Console`ウィンドウにログが出ていれば成功です。
matrix scan rateが1秒に一回流れており、キーを叩くと表示されれば正しく認識されています。

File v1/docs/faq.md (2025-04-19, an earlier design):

# FAQ（よくある質問）

追加したい質問や要望がある場合は、[マシュマロ](https://marshmallow-qa.com/9p7qcrd1b86zk8d)や[issue](https://github.com/esplo/cue2keys_resources/issues)を立てていただけると助かります。

## キースイッチ・キーキャップは変更できますか？

はい、もちろん変更できます！
注意点として：
- キースイッチはCherry MX互換のみ対応しており、Low Profileには対応していません
- ロウスタッガード（行をずらした配列）で構成する場合、キースイッチが通常と90°回転するため、事前にキーキャップとの互換性を確認してください

## キーのリマップはできますか？

はい、[REMAP](https://remap-keys.app/)などのブラウザ上で動作するVIA対応ツールで簡単に設定可能です。
詳しい手順は[キーマップガイド](./keymap_guide.md)をご覧ください。

## どの接続方式に対応していますか？

現在、PCやタブレットとの接続はUSB-AまたはUSB-Cでの有線接続に対応しています。

## どのOSに対応していますか？

Mac OS、Windows、Android、iOS（iPad OS）での動作を確認しています。

## 購入からどのくらいで届きますか？

在庫がある場合は約2週間、受注生産の場合は約2ヶ月ほどのお時間をいただいています。
くっつきーは小規模な進化中のプロジェクトのため、基本的には在庫がありません。
製造数の参考にできるので、ぜひBOOTHの「入荷お知らせメールを受け取る」をクリックください。
最新の販売状況は[SNS](https://linktr.ee/cue2keys)でも投稿しますので、そちらもご確認ください。

## ケーブルは付属しますか？

はい、各モジュールには購入時に動作確認済みのケーブルが付属します。

用途に合わない場合は以下のことが可能です：
- 各モジュールの詳細ページでケーブル仕様を確認し、互換性のあるケーブルに変更する
- USBケーブルには一般的な延長ケーブルが利用可能（ただし、長すぎると動作が不安定になる可能性があるため、できるだけ短いものを使用してください）

## プログラミングやはんだ付けは必要ですか？

いいえ、くっつきーのモジュールは接続するだけで動作します。

ただし、まだ世に存在しないモジュールや機能を追加したい場合には、これらのスキルが必要になることがあります。
作りたいものがあるけれど経験がない場合は、[issue](https://github.com/esplo/cue2keys_resources/issues)で同じ目標を持つ仲間を探してみるのも良いでしょう。

## 他のモジュールが欲しいです

[マシュマロ](https://marshmallow-qa.com/9p7qcrd1b86zk8d)や[issue](https://github.com/esplo/cue2keys_resources/issues)で既存のリクエストを確認し、まだ無い場合はお気軽に新しいリクエストを追加してください。

## ケーブルが乱雑になります。すっきりさせる方法はありますか？

モジュールとハブの間は多数のケーブルが必要なため、見た目をすっきりさせるには工夫が必要です。

おすすめの方法：
- ハブを配置する際、距離の遠い側のポートに接続することでケーブルが固定されやすくなります
- ある程度の高さでチルティングやテンティング（傾斜）を付ける場合は、ハブをキーボード土台の下に収納できます
- 土台の穴と位置が合う場合は、そこを通してケーブルを固定し、飛び出ないようにするのも効果的です

## うまく認識しません。どうすればよいですか？

まずは[ビルドガイド](./build_guide.md)の手順を再確認してください。

問題解決のためのチェックリスト：
1. ファームウェア書き込み後に認識されない場合は、ペンダントとPCの接続ケーブルを一度抜き差ししてください（ペンダントのRSTボタンだけでは完全に初期化されないことがあります）
2. ディスプレイが表示されている場合は、認識されているモジュール数が実際の接続数と合っているか確認してください
3. 認識されていない場合、以下を確認：
   - ケーブルがしっかりと接続されているか
   - ケーブル自体に問題がないか（例：HYケーブルで一本の線が抜けているなど）
   - 同一チャンネル内で重複したアドレスが設定されていないか

ディスプレイに表示される`#Device`の数が実際の接続数と合っていれば、モジュールは正しく認識されています。

また、キーコードが割り当てられていない場合、キーを押しても何も反応がないように見えますので、キーマップも確認してください。

問題が解決しない場合は、SNSや[マシュマロ](https://marshmallow-qa.com/9p7qcrd1b86zk8d)、[issue](https://github.com/esplo/cue2keys_resources/issues)にてご連絡ください。

## モジュールの設定を変更したい（トラックボールの角度、速度など）

トラックボールの角度、速度、スクロールの反転、ノブの解像度など、多くの設定が調整可能です。

設定方法：
1. まず[カスタムキーコード](./custom_keycodes.md)の一覧を確認し、必要な設定項目があるか探してください
2. 変更したい項目が見つからない場合は、[マシュマロ](https://marshmallow-qa.com/9p7qcrd1b86zk8d)や[issue](https://github.com/esplo/cue2keys_resources/issues)にてリクエストをお寄せください

## モジュールが上手くくっつかない場合は？

製造の都合上、成形精度にばらつきがあり、うまく噛み合わない場合や逆に緩すぎる場合があります。
動作に支障がある場合は、[X（旧Twitter）](https://x.com/cue2keys)のDM、BOOTHの購入者メッセージ、[マシュマロ](https://marshmallow-qa.com/9p7qcrd1b86zk8d)や[issue](https://github.com/esplo/cue2keys_resources/issues)などでご連絡ください。

## ドキュメントに記載のある機能が見つかりません

まずは[ファームウェアガイド](./firmware_guide.md)を参照し、最新のファームウェアに更新してみてください。
それでも機能が見つからない場合は、ドキュメントの記載に誤りがある可能性があります。
お気軽にご連絡いただければ幸いです。

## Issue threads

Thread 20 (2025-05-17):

小数キーのモジュール追加

HiroakiShimakura, 2025-05-17:
1キー、2キー、3キーのモジュールの追加をお願いしたいです。

esplo, 2025-05-17:
ご要望いただき誠にありがとうございます。

現在、これら数が少ないキーモジュールの実装は技術的に難しく、4/5キーと同様には行えない状況です。
基板上の必要なパーツ配置の制約により、4キー未満のモジュールでは、実際のキー数に比べて大きな余白が必要となります。例えば、1キーモジュールの場合でも、2キー分のスペースが必要になってしまいます。
（なお、パーツの削減や専有面積の縮小については日々調査を続けており、進展があればより小型のモジュール実装が可能になるかもしれません）

このような設計上の制約から、モジュールの外形がキー数に対して+0.5U近く大きくなってしまいますが、そのような形でも想定される用途として問題はないでしょうか？

HiroakiShimakura, 2025-05-17:
全く問題ないです。私事で恐縮ですが、30〜40%キーボードを使用しており、これらの分割だと左右3x5(ないし6)+親指キーがベースになります。この場合、3キーのモジュールがあるとベースの配置を作りやすく、1~2キーのモジュールがあると親指キーの配置にこだわれるようになるため、今回リクエストをしました。

くっつきーは、「より自由な配置のキーボードを組みたい、けど設計を行うのは億劫」という人のニーズを満たせる素晴らしいプロダクトだと思います。
自作キーボード入門として選ばれることが多いCorneやKeyballの次のステップとして、「自分で配置をこだわりたい」と考えたとき、3キーのモジュールについては特に需要があるように思いますので、ぜひ検討いただきたいです。

esplo, 2025-05-17:
ありがとうございます。具体的なユースケースをご説明いただき大変参考になりました。また、嬉しいコメントもいただきありがとうございます。

ミニマルなキーボード構成のニーズは仰る通りあるかと思いますし、レイアウトの柔軟性を高めるためにも追加できると良さそうに感じます。
実現できるかどうか検討を進めてみたいと思います。

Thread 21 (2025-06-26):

ペンダントの非表示時の復旧

icchie, 2025-06-26:
遊舎工房の委託品でスターターセットDX を購入して、その後 Booth で別途 5key などを追加購入させていただきました。
自分の好みのキー配置を作りペンダントに接続したのですが、ペンダントのディスプレイ表示が出なくなり、キー操作なども出来ない状態になってしまいました。

チャンネル設定を見返しても特に不整合はない状態でして、ファームウェアガイドに従ってファームウェアアップロードやリセットボタン等での復旧を試みようとしたのですが、ブートローダーのマウント自体が出来ない状態でした。

ペンダントのカバーを開けると RST ボタンの二度押し後に明るい LED 点灯は確認出来るのですが、 繋いでいる PC 自体にマウントされている様子がない次第です。

この状態からの復旧手順があればお教えいただきたい次第です。
よろしくお願いいたします。

esplo, 2025-06-26:
ご購入およびご連絡いただき誠にありがとうございます。
ペンダントのディスプレイが表示されないとのことで、ご不便をおかけしております。

ブートローダーがマウントされない点まで調査いただいているのでお手数ではありますが、原因切り分けのため下記手順をお試しいただき、結果を共有いただけますと幸いです。

1. もしUSBハブや切替器などを介している場合は、直接PCに接続して挙動が変わるかお試しください。また、別のPCがある場合は、変化があるかお試しください。
2. ペンダントに接続されているモジュール（ハブ、トラックボール）を全て外してPCと繋ぎ直し、挙動が変わるかお試しください。
3. ペンダントとPCを接続しているケーブルを変更してお試しください。ハブに繋がっているケーブルとは同一なので、そちらでお確かめいただくと簡単です。

icchie, 2025-06-27:
ご確認ありがとうございます

> 1. もしUSBハブや切替器などを介している場合は、直接PCに接続して挙動が変わるかお試しください。また、別のPCがある場合は、変化があるかお試しください。

Mac なので USB-A が本体になくハブ経由で繋いでいたのですが、手持ちで C to C ケーブルで本体に繋いでところ無事に起動しました。
ありがとうございます。
その後、ハブ経由で再度試みたところ表示されましたが、切れてしまうこともありハブ側でのなんらかのタイミング問題がありそうな様子でした。

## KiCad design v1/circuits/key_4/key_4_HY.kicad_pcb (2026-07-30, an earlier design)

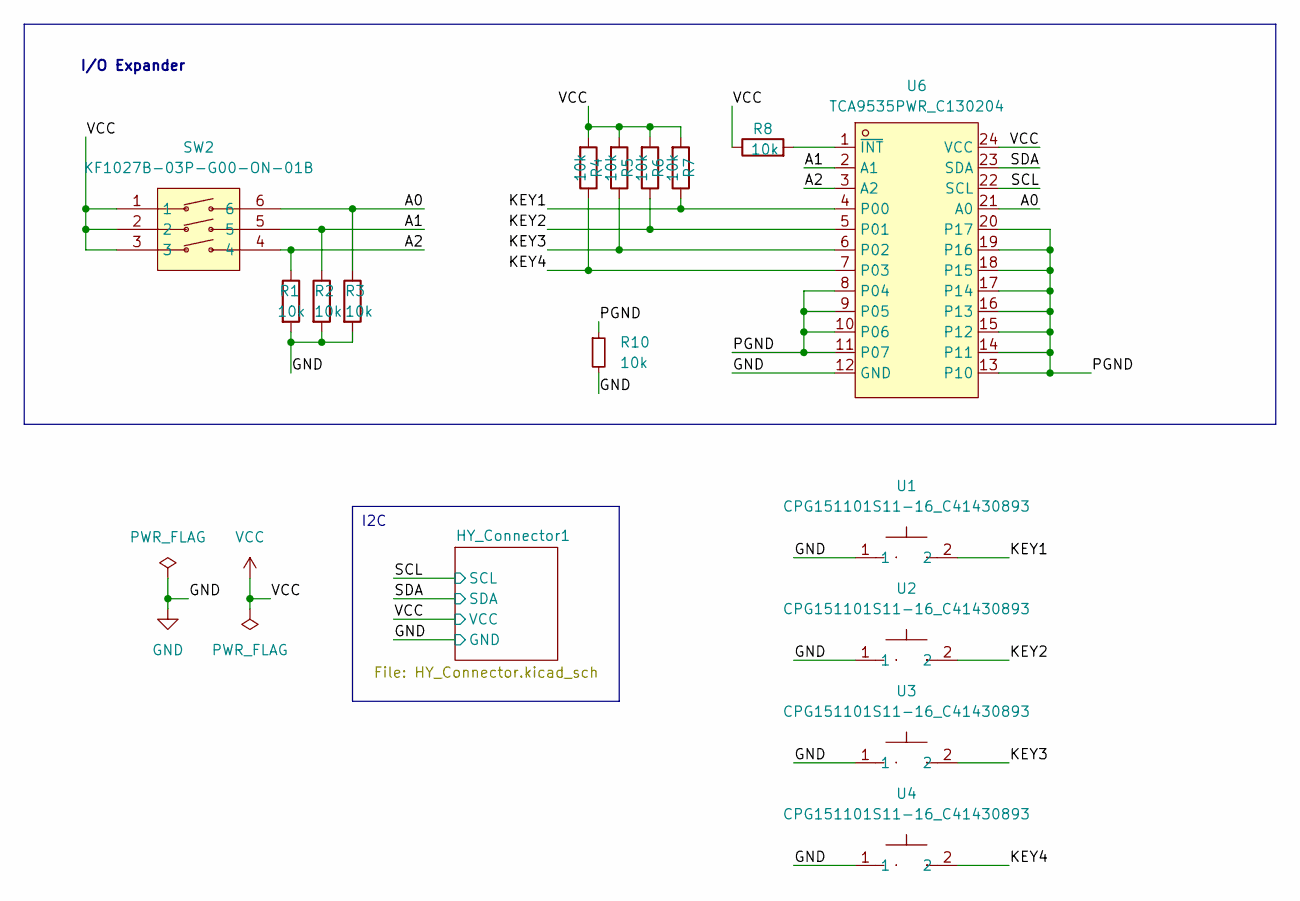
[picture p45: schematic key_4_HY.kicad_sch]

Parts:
R1, R2, R3, R4, R5, R6, R7, R8, R10: 10k; R_0805_2012Metric; LCSC Part C17414
SW2: KF1027B-03P-G00-ON-01B; SW-SMD_6P-L8.6-W6.2-P2.54-LS9.9; LCSC Part C976365
U1, U2, U3, U4: CPG151101S11-16_C41430893; SW_Hotswap_Kailh_MX_1.00u; LCSC Part C41430893
U6: TCA9535PWR_C130204; TSSOP-24_L7.8-W4.4-P0.65-LS6.4-BL; LCSC Part C130204

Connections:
/A0: R3.1, SW2.6, U6.21 (A0)
/A1: R2.1, SW2.5, U6.2 (A1)
/A2: R1.1, SW2.4, U6.3 (A2)
/KEY1: R7.1, U1.2, U6.4 (P00)
/KEY2: R6.1, U2.2, U6.5 (P01)
/KEY3: R5.1, U3.2, U6.6 (P02)
/KEY4: R4.1, U4.2, U6.7 (P03)
/PGND: R10.1, U6.8 (P04), U6.9 (P05), U6.10 (P06), U6.11 (P07), U6.13 (P10), U6.14 (P11), U6.15 (P12), U6.16 (P13), U6.17 (P14), U6.18 (P15), U6.19 (P16), U6.20 (P17)
/SCL: U6.22 (SCL); also elsewhere on the board
/SDA: U6.23 (SDA); also elsewhere on the board
GND: R1.2, R2.2, R3.2, R10.2, U1.1, U2.1, U3.1, U4.1, U6.12 (GND); also elsewhere on the board
unnamed: R8.2, U6.1 (~INT)
VCC: R4.2, R5.2, R6.2, R7.2, R8.1, SW2.1, SW2.2, SW2.3, U6.24 (VCC); also elsewhere on the board

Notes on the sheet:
I2C
I/O Expander

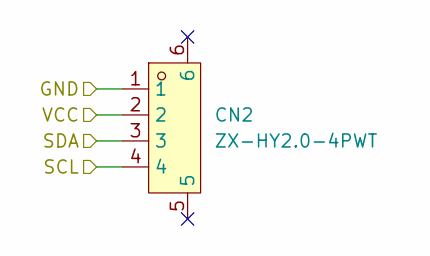
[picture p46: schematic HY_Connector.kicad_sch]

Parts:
CN2: ZX-HY2.0-4PWT; CONN-SMD_4P-P2.00_ZX-HY2.0-4PWT; LCSC Part C7429571

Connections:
/SCL: CN2.4; also elsewhere on the board
/SDA: CN2.3; also elsewhere on the board
GND: CN2.1; also elsewhere on the board
VCC: CN2.2; also elsewhere on the board

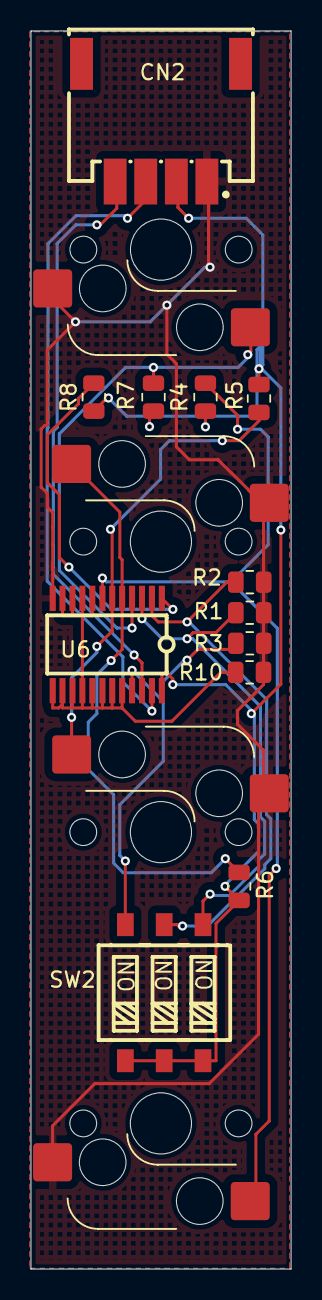
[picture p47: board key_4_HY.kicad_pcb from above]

Board: 2 copper layers, 17.0 x 81.0 mm, 16 parts (4 on the bottom side), 13 nets.

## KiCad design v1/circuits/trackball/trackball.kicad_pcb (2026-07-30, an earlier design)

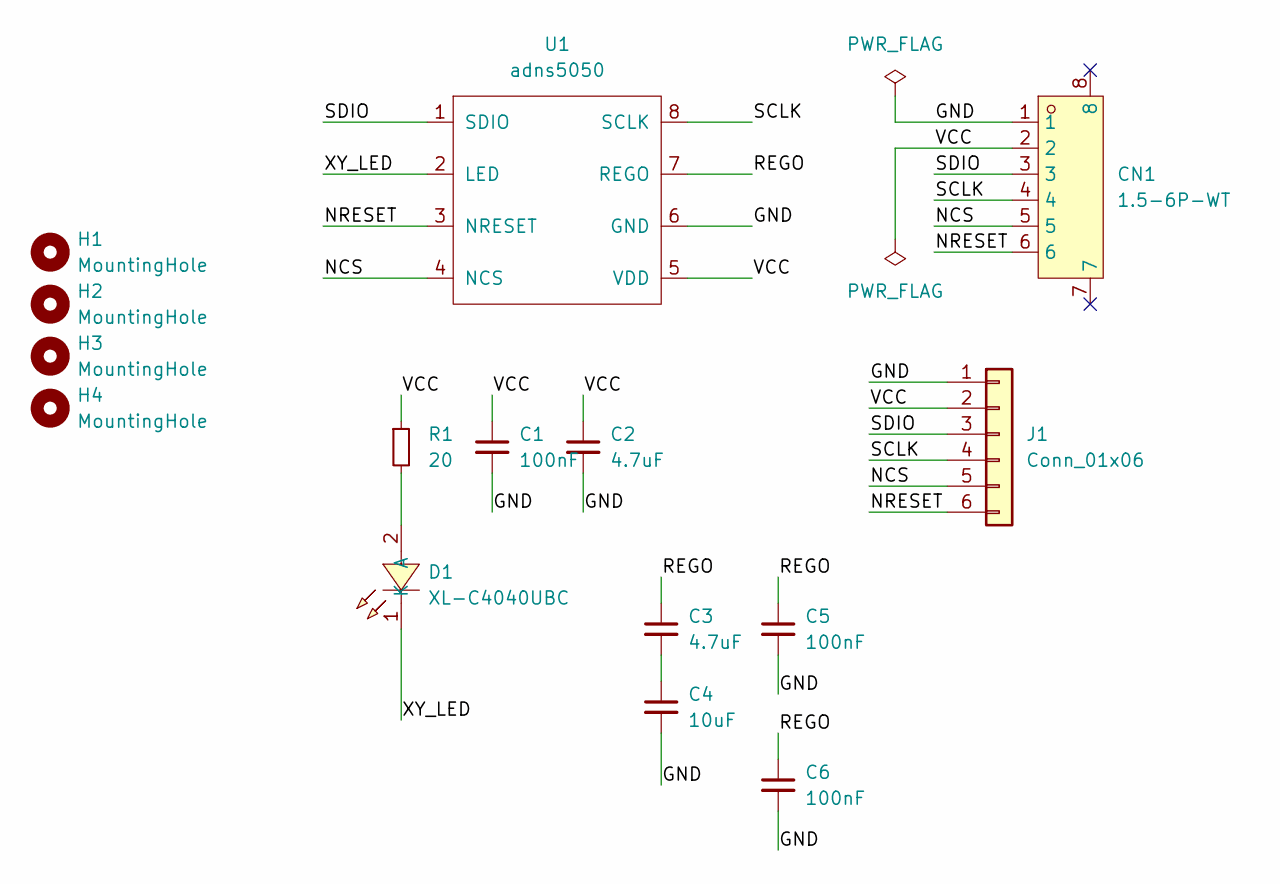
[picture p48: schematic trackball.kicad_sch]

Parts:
C1, C5, C6: 100nF; C_0603_1608Metric; LCSC C14663
C2, C3: 4.7uF; C_0603_1608Metric; LCSC C19666
C4: 10uF; C_0603_1608Metric; LCSC C19702
CN1: 1.5-6P-WT; CONN-SMD_1.5-6P-WT; LCSC Part C722672
D1: XL-C4040UBC; LED-SMD_L4.0-W3.6_A67F-U2BA-1-3A4B-30-R33; LCSC Part C7545685
H1, H2, H3, H4: MountingHole; MountingHole_2.5mm
J1: Conn_01x06; PinHeader_1x06_P2.54mm_Vertical
R1: 20; C_0805_2012Metric; LCSC C17544
U1: adns5050; ADNS5050_v2_2

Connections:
/GND: C1.2, C2.2, C4.2, C5.2, C6.2, CN1.1, J1.1, U1.6 (GND)
/NCS: CN1.5, J1.5, U1.4 (NCS)
/NRESET: CN1.6, J1.6, U1.3 (NRESET)
/REGO: C3.1, C5.1, C6.1, U1.7 (REGO)
/SCLK: CN1.4, J1.4, U1.8 (SCLK)
/SDIO: CN1.3, J1.3, U1.1 (SDIO)
/VCC: C1.1, C2.1, CN1.2, J1.2, R1.1, U1.5 (VDD)
/XY_LED: D1.1 (K), U1.2 (LED)
unnamed: C3.2, C4.1
unnamed: D1.2 (A), R1.2

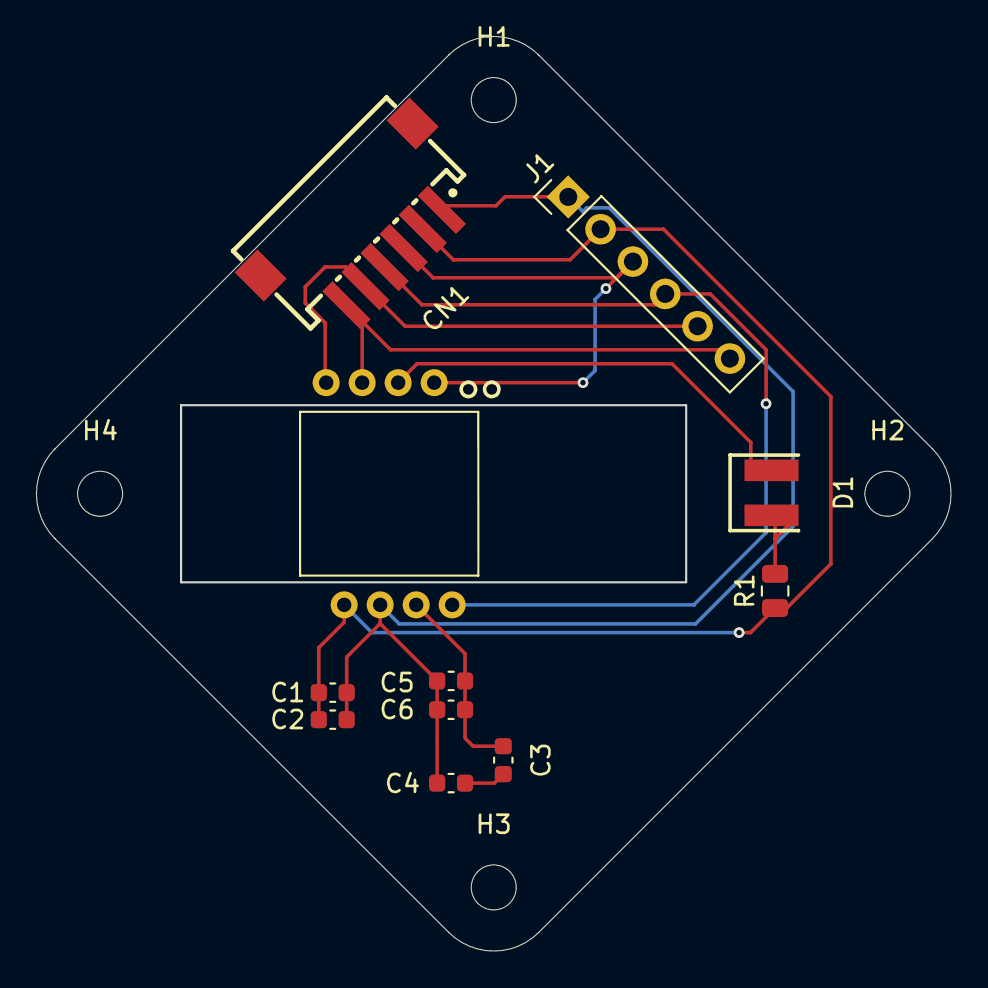
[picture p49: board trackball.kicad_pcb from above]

Board: 2 copper layers, 50.8 x 50.8 mm, 15 parts (0 on the bottom side), 10 nets.

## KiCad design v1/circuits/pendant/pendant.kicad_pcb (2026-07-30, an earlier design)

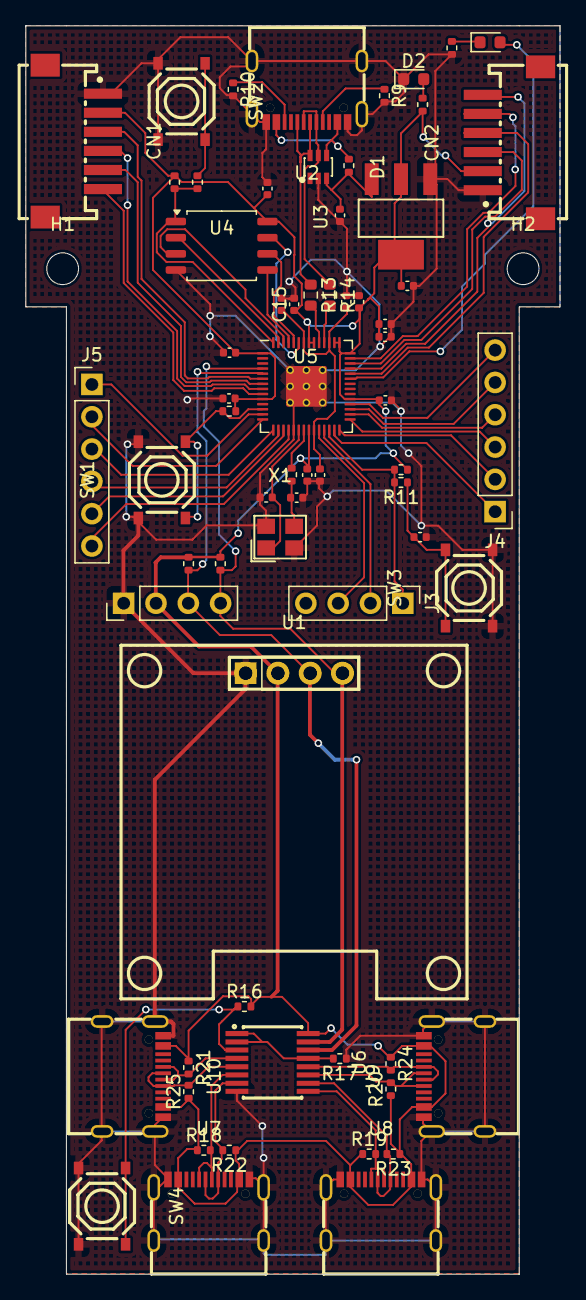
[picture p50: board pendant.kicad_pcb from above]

Board: 2 copper layers, 42.0 x 98.1 mm, 69 parts (0 on the bottom side), 61 nets.

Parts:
C1, C4: 10u; C_0402_1005Metric
C2, C3: 15p; C_0402_1005Metric
C5, C6, C7, C8, C10, C11, C12, C13, C15, C16, C17: 100n; C_0402_1005Metric
C9, C14: 1u; C_0402_1005Metric
CN1, CN2: 1.5-6P-WT; CONN-SMD_1.5-6P-WT
D1: SMF05CT1G; SOT-363_L2.0-W1.3-P0.65-LS2.1-BR
D2, D3: LED; LED_0603_1608Metric
H1, H2: MountingHole; MountingHole_2.5mm
J1, J2, J3: Conn_01x04; PinHeader_1x04_P2.54mm_Vertical
J4, J5: Conn_01x06; PinHeader_1x06_P2.54mm_Vertical
R1, R6, R8, R12, R16, R17: 10k; R_0402_1005Metric
R2, R3, R5, R7, R11, R15, R18, R19, R20, R21, R22, R23, R24, R25: 1k; R_0402_1005Metric
R4: 0; R_0402_1005Metric
R9, R10: 5.1K; R_0402_1005Metric
R13, R14: 27; R_0603_1608Metric
SW1, SW2, SW3, SW4: TS-1187A-B-A-B; SW-SMD_4P-L5.1-W5.1-P3.70-LS6.5-TL_H1.5
U1: HS96L03W2C03; OLED-TH_L27.8-W27.2-P2.54_C9900033791
U2, U7, U8, U9, U10: GT-USB-7010ASV; USB-C-SMD_G-SWITCH_GT-USB-7010ASV
U3: AMS1117-3.3; SOT-223-3_L6.5-W3.4-P2.30-LS7.0-BR
U4: W25Q128JVS; SOIC-8_5.23x5.23mm_P1.27mm
U5: RP2040; RP2040-QFN-56
U6: PCA9546APW,118; SOP-16_L5.0-W4.4-P0.65-LS6.4-BL
X1: X322512MSB4SI; CRYSTAL-SMD_4P-L3.2-W2.5-BL

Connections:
+1V1: C7.1, C8.1, C9.1, U5.23 (DVDD), U5.45 (VREG_VOUT), U5.50 (DVDD)
+3V3: C4.1, C5.1, C10.1, C11.1, C12.1, C13.1, C14.1, C15.1, C16.1, C17.1, CN1.2, CN2.2, J1.2, J2.2, R1.1, R2.1, R3.1, R6.1, R8.1, R12.1, R16.2, R18.1, R19.1, R20.1, R21.1, R22.1, R23.1, R24.1, R25.1, U1.2 (VCC), U3.2 (VOUT), U3.4 (VOUT), U4.8 (VCC), U5.1 (IOVDD), U5.10 (IOVDD), U5.22 (IOVDD), U5.33 (IOVDD), U5.42 (IOVDD), U5.43 (ADC_AVDD), U5.44 (VREG_IN), U5.48 (USB_VDD), U5.49 (IOVDD), U6.16 (VDD), U7.A4B9 (VBUS), U7.B4A9 (VBUS), U8.A4B9 (VBUS), U8.B4A9 (VBUS), U9.A4B9 (VBUS), U9.B4A9 (VBUS), U10.A4B9 (VBUS), U10.B4A9 (VBUS)
+5V: C1.1, D1.3, R4.2, U3.3 (VIN)
/C1_SPI0_CSn: CN1.5, U5.7 (GPIO5)
/C1_SPI0_RX: CN1.3, U5.6 (GPIO4)
/C1_SPI0_SCK: CN1.4, U5.8 (GPIO6)
/C1_SPI0_TX: CN1.6, U5.9 (GPIO7)
/C1_SPI1_CSn: CN2.5, U5.41 (GPIO29_ADC3)
/C1_SPI1_RX: CN2.3, U5.40 (GPIO28_ADC2)
/C1_SPI1_SCK: CN2.4, U5.38 (GPIO26_ADC0)
/C1_SPI1_TX: CN2.6, U5.39 (GPIO27_ADC1)
/I2CMUX/A2: R17.2, U6.1 (A0), U6.2 (A1), U6.13 (A2)
/I2CMUX/RST: R16.1, SW4.1 (A), SW4.2 (B), U6.3 (/RESET)
/I2CMUX/SC0: R25.2, U6.5 (SC0), U10.A6 (DP1), U10.B6 (DP2)
/I2CMUX/SC1: R22.2, U6.7 (SC1), U7.A6 (DP1), U7.B6 (DP2)
/I2CMUX/SC2: R23.2, U6.10 (SC2), U8.A6 (DP1), U8.B6 (DP2)
/I2CMUX/SC3: R24.2, U6.12 (SC3), U9.A6 (DP1), U9.B6 (DP2)
/I2CMUX/SD0: R21.2, U6.4 (SD0), U10.A7 (DN1), U10.B7 (DN2)
/I2CMUX/SD1: R18.2, U6.6 (SD1), U7.A7 (DN1), U7.B7 (DN2)
/I2CMUX/SD2: R19.2, U6.9 (SD2), U8.A7 (DN1), U8.B7 (DN2)
/I2CMUX/SD3: R20.2, U6.11 (SD3), U9.A7 (DN1), U9.B7 (DN2)
/OLED_SW: R1.2, SW1.3 (C), SW1.4 (D), U5.12 (GPIO9)
/RP2040/GPIO10: J5.1, U5.13 (GPIO10)
/RP2040/GPIO11: J5.2, U5.14 (GPIO11)
/RP2040/GPIO12: J5.3, U5.15 (GPIO12)
/RP2040/GPIO13: J5.4, U5.16 (GPIO13)
/RP2040/GPIO14: J5.5, U5.17 (GPIO14)
/RP2040/GPIO15: J5.6, U5.18 (GPIO15)
/RP2040/GPIO16: J4.1, U5.27 (GPIO16)
/RP2040/GPIO17: J4.2, U5.28 (GPIO17)
/RP2040/GPIO18: J4.3, U5.29 (GPIO18)
/RP2040/GPIO19: J4.4, U5.30 (GPIO19)
/RP2040/GPIO20: J4.5, U5.31 (GPIO20)
/RP2040/GPIO21: J4.6, U5.32 (GPIO21)
/RP2040/LED: D3.2 (A), U5.37 (GPIO25)
/RP2040/QSPI_SCLK: U4.6 (CLK), U5.52 (QSPI_SCLK)
/RP2040/QSPI_SD0: U4.5 (DI(IO0)), U5.53 (QSPI_SD0)
/RP2040/QSPI_SD1: U4.2 (DO(IO1)), U5.55 (QSPI_SD1)
/RP2040/QSPI_SD2: U4.3 (IO2), U5.54 (QSPI_SD2)
/RP2040/QSPI_SD3: U4.7 (IO3), U5.51 (QSPI_SD3)
/RP2040/QSPI_SS: R5.1, R6.2, U4.1 (~CS), U5.56 (QSPI_SS)
/RP2040/RUN: J3.1, R11.2, R12.2, U5.26 (RUN)
/RP2040/SWCLK: J3.3, U5.24 (SWCLK)
/RP2040/SWD: J3.2, U5.25 (SWD)
/RP2040/USB_D+: D1.6, R13.1, U2.A6 (DP1), U2.B6 (DP2)
/RP2040/USB_D-: D1.5, R14.1, U2.A7 (DN1), U2.B7 (DN2)
/RP2040/VBUS: D1.4, R4.1, U2.A4B9 (VBUS), U2.B4A9 (VBUS)
/RP2040/XIN: C2.1, U5.20 (XIN), X1.1 (OSC1)
/RP2040/XOUT: R7.1, U5.21 (XOUT)
/RP2040/~USB_BOOT: R5.2, SW2.1 (A), SW2.2 (B)
/SCL: J1.3, J2.3, R2.2, U1.3 (SCL), U5.5 (GPIO3), U6.14 (SCL)
/SDA: J1.4, J2.4, R3.2, U1.4 (SDA), U5.4 (GPIO2), U6.15 (SDA)
GND: C1.2, C2.2, C3.2, C4.2, C5.2, C6.2, C7.2, C8.2, C9.2, C10.2, C11.2, C12.2, C13.2, C14.2, C15.2, C16.2, C17.2, CN1.1, CN2.1, D1.2, D2.1 (K), J1.1, J2.1, R9.2, R10.2, R15.2, R17.1, SW1.1 (A), SW1.2 (B), SW2.3 (C), SW2.4 (D), SW3.3 (C), SW3.4 (D), SW4.3 (C), SW4.4 (D), U1.1 (GND), U2.1 (SHELL), U2.2 (SHELL), U2.3 (SHELL), U2.4 (SHELL), U2.A1B12 (GND), U2.B1A12 (GND), U3.1 (GND), U4.4 (GND), U5.19 (TESTEN), U5.57 (GND), U6.8 (VSS), U7.1 (SHELL), U7.2 (SHELL), U7.3 (SHELL), U7.4 (SHELL), U7.A1B12 (GND), U7.B1A12 (GND), U8.1 (SHELL), U8.2 (SHELL), U8.3 (SHELL), U8.4 (SHELL), U8.A1B12 (GND), U8.B1A12 (GND), U9.1 (SHELL), U9.2 (SHELL), U9.3 (SHELL), U9.4 (SHELL), U9.A1B12 (GND), U9.B1A12 (GND), U10.1 (SHELL), U10.2 (SHELL), U10.3 (SHELL), U10.4 (SHELL), U10.A1B12 (GND), U10.B1A12 (GND), X1.2 (GND), X1.4 (GND)
unnamed: D2.2 (A), R8.2
unnamed: D3.1 (K), R15.1
unnamed: C6.1, R11.1, SW3.1 (A), SW3.2 (B)
unnamed: R9.1, U2.A5 (CC1)
unnamed: R10.1, U2.B5 (CC2)
unnamed: R14.2, U5.46 (USB_DM)
unnamed: R13.2, U5.47 (USB_DP)
unnamed: C3.1, R7.2, X1.3 (OSC2)

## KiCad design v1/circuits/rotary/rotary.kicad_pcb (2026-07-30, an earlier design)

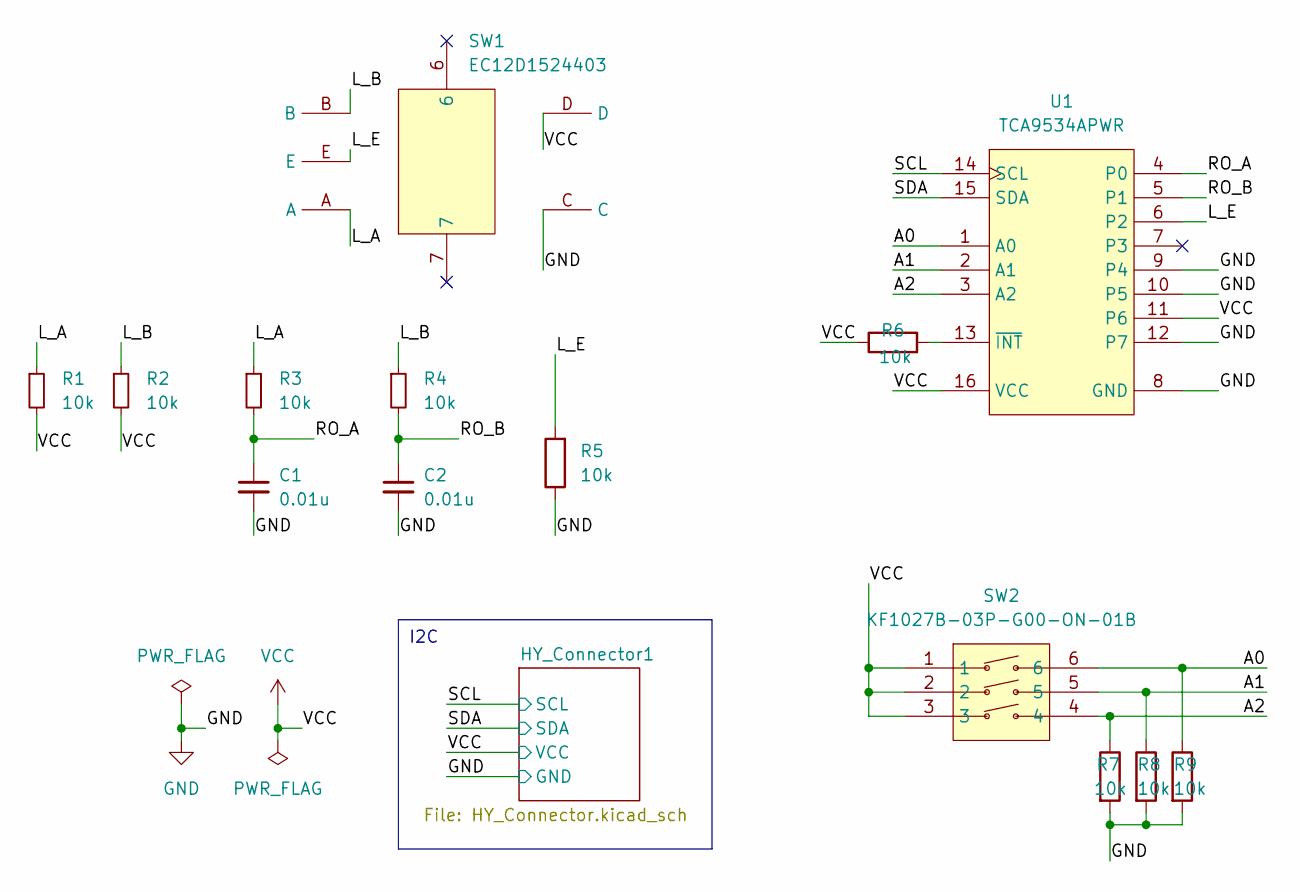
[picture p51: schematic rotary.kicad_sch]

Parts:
C1, C2: 0.01u; C_0402_1005Metric; LCSC Part C15195
R1, R2, R3, R4, R5, R6, R7, R8, R9: 10k; R_0402_1005Metric; LCSC Part C17414
SW1: EC12D1524403; SW-TH_EC12D1524403; LCSC Part C112349
SW2: KF1027B-03P-G00-ON-01B; SW-SMD_6P-L8.6-W6.2-P2.54-LS9.9; LCSC Part C976365
U1: TCA9534APWR; TSSOP-16_L5.0-W4.4-P0.65-LS6.4-BL; LCSC Part C206010

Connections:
/A0: R9.1, SW2.6, U1.1 (A0)
/A1: R8.1, SW2.5, U1.2 (A1)
/A2: R7.1, SW2.4, U1.3 (A2)
/L_A: R1.1, R3.1, SW1.A
/L_B: R2.1, R4.1, SW1.B
/L_E: R5.2, SW1.E, U1.6 (P2)
/RO_A: C1.1, R3.2, U1.4 (P0)
/RO_B: C2.1, R4.2, U1.5 (P1)
/SCL: U1.14 (SCL); also elsewhere on the board
/SDA: U1.15 (SDA); also elsewhere on the board
GND: C1.2, C2.2, R5.1, R7.2, R8.2, R9.2, SW1.C, U1.8 (GND), U1.9 (P4), U1.10 (P5), U1.12 (P7); also elsewhere on the board
unnamed: R6.2, U1.13 (~INT)
VCC: R1.2, R2.2, R6.1, SW1.D, SW2.1, SW2.2, SW2.3, U1.11 (P6), U1.16 (VCC); also elsewhere on the board

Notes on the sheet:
I2C


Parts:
CN2: ZX-HY2.0-4PWT; CONN-SMD_4P-P2.00_ZX-HY2.0-4PWT; LCSC Part C7429571

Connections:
/SCL: CN2.4; also elsewhere on the board
/SDA: CN2.3; also elsewhere on the board
GND: CN2.1; also elsewhere on the board
VCC: CN2.2; also elsewhere on the board

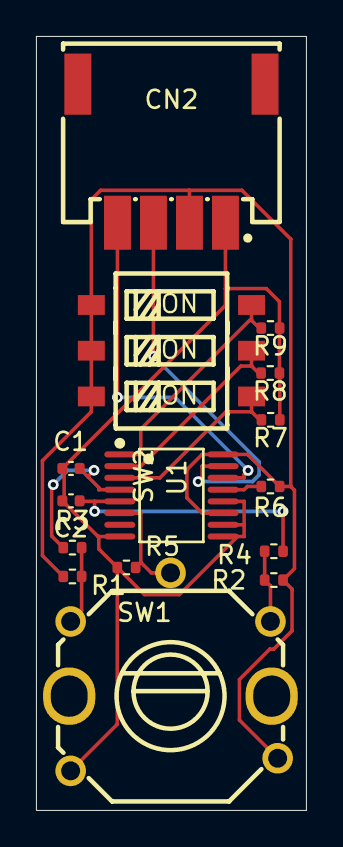
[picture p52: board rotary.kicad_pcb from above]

Board: 2 copper layers, 15.0 x 43.0 mm, 15 parts (0 on the bottom side), 13 nets.

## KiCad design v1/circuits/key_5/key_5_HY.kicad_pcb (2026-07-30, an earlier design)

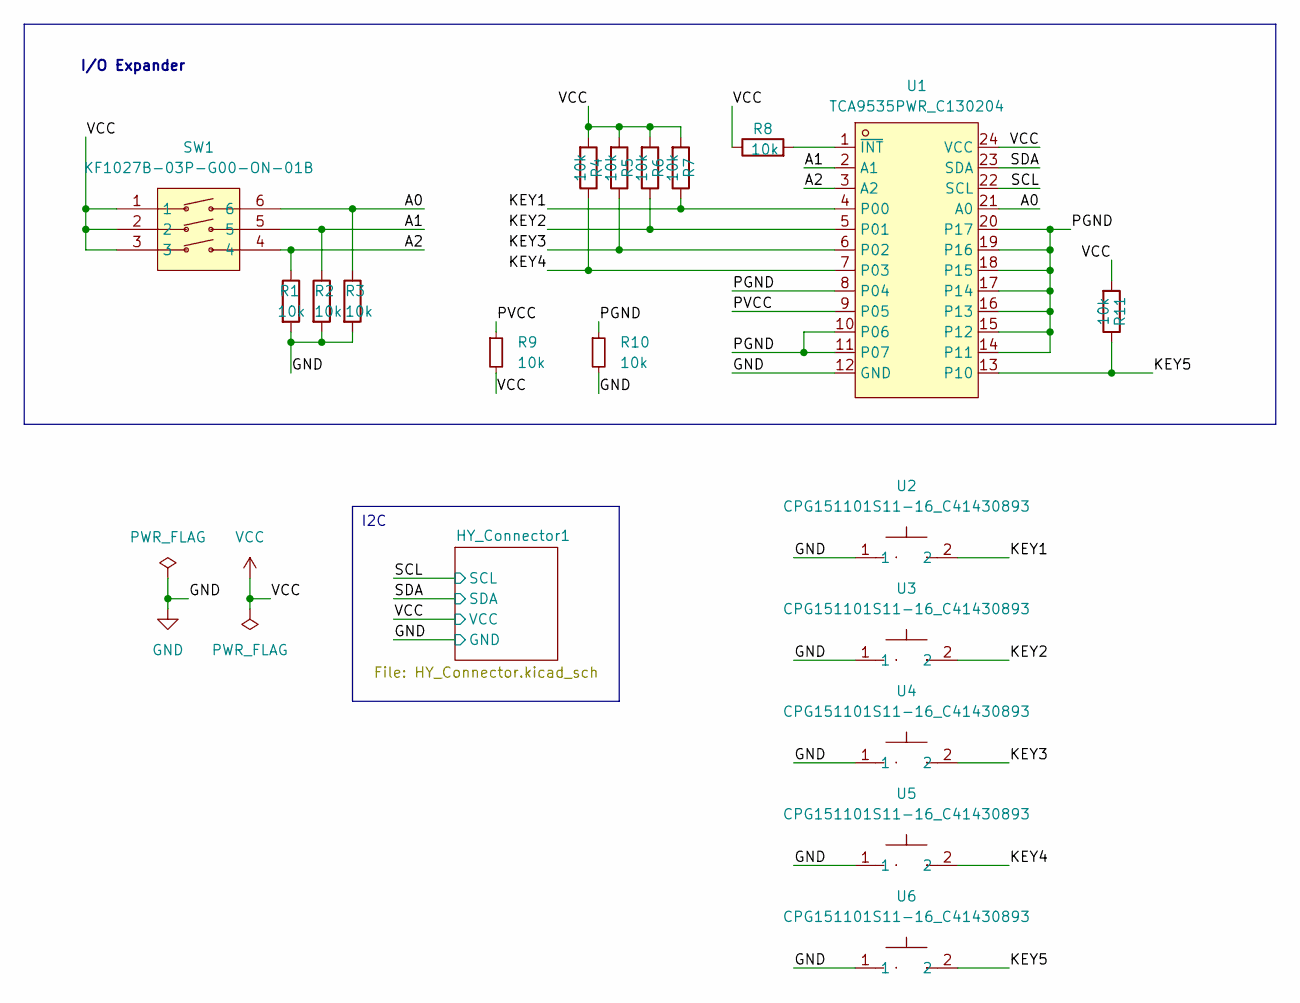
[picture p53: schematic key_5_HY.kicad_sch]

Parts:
R1, R2, R3, R4, R5, R6, R7, R8, R9, R10, R11: 10k; R_0805_2012Metric; LCSC Part C17414
SW1: KF1027B-03P-G00-ON-01B; SW-SMD_6P-L8.6-W6.2-P2.54-LS9.9; LCSC Part C976365
U1: TCA9535PWR_C130204; TSSOP-24_L7.8-W4.4-P0.65-LS6.4-BL; LCSC Part C130204
U2, U3, U4, U5, U6: CPG151101S11-16_C41430893; SW_Hotswap_Kailh_MX_1.00u; LCSC Part C41430893

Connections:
/A0: R3.1, SW1.6, U1.21 (A0)
/A1: R2.1, SW1.5, U1.2 (A1)
/A2: R1.1, SW1.4, U1.3 (A2)
/KEY1: R7.1, U1.4 (P00), U2.2
/KEY2: R6.1, U1.5 (P01), U3.2
/KEY3: R5.1, U1.6 (P02), U4.2
/KEY4: R4.1, U1.7 (P03), U5.2
/KEY5: R11.1, U1.13 (P10), U6.2
/PGND: R10.1, U1.8 (P04), U1.10 (P06), U1.11 (P07), U1.14 (P11), U1.15 (P12), U1.16 (P13), U1.17 (P14), U1.18 (P15), U1.19 (P16), U1.20 (P17)
/PVCC: R9.1, U1.9 (P05)
/SCL: U1.22 (SCL); also elsewhere on the board
/SDA: U1.23 (SDA); also elsewhere on the board
GND: R1.2, R2.2, R3.2, R10.2, U1.12 (GND), U2.1, U3.1, U4.1, U5.1, U6.1; also elsewhere on the board
unnamed: R8.2, U1.1 (~INT)
VCC: R4.2, R5.2, R6.2, R7.2, R8.1, R9.2, R11.2, SW1.1, SW1.2, SW1.3, U1.24 (VCC); also elsewhere on the board

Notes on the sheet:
I2C
I/O Expander

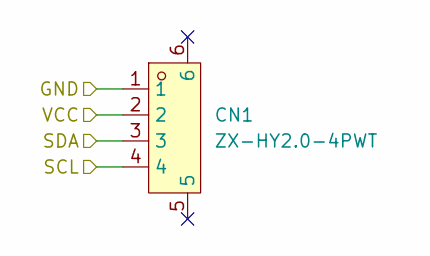
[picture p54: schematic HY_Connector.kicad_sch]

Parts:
CN1: ZX-HY2.0-4PWT; CONN-SMD_4P-P2.00_ZX-HY2.0-4PWT; LCSC Part C7429571

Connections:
/SCL: CN1.4; also elsewhere on the board
/SDA: CN1.3; also elsewhere on the board
GND: CN1.1; also elsewhere on the board
VCC: CN1.2; also elsewhere on the board

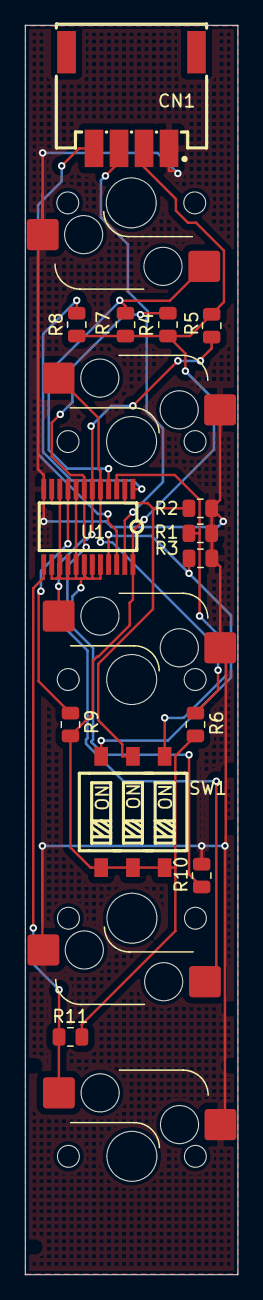
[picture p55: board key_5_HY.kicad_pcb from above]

Board: 2 copper layers, 17.0 x 100.0 mm, 19 parts (5 on the bottom side), 15 nets.

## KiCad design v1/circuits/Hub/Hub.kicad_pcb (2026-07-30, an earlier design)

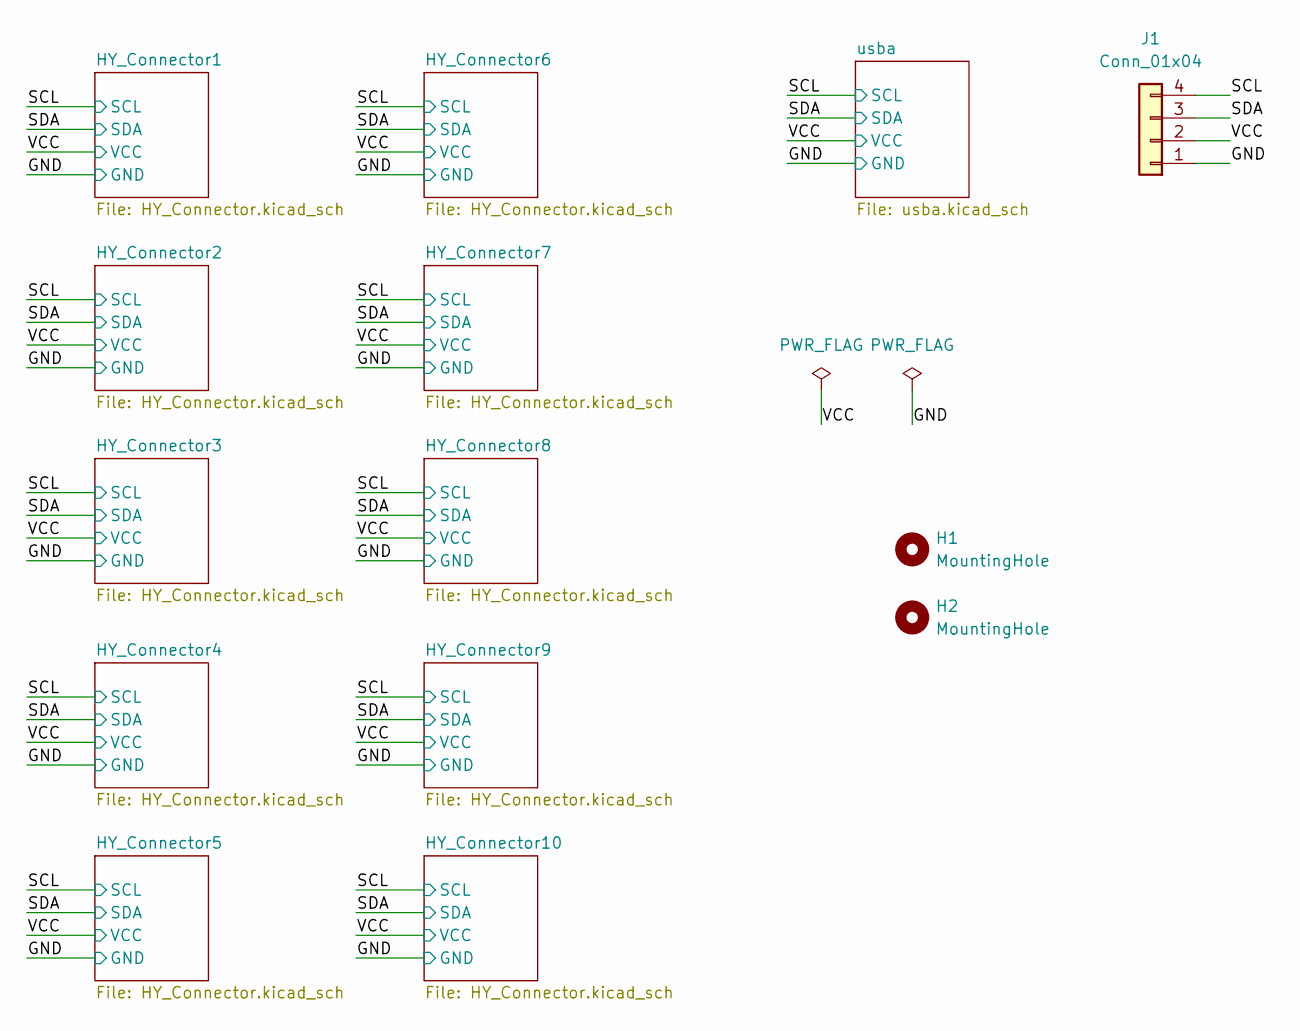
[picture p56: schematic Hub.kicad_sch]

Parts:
H1, H2: MountingHole; MountingHole_2.5mm
J1: Conn_01x04; PinHeader_1x04_P2.54mm_Vertical

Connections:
/GND: J1.1; also elsewhere on the board
/SCL: J1.4; also elsewhere on the board
/SDA: J1.3; also elsewhere on the board
/VCC: J1.2; also elsewhere on the board


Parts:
U3: BX-HY2.0-4PWT; CONN-SMD_4P-P2.0_BX-HY2.0-4PWT; LCSC Part C18077773

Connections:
/GND: U3.1, U3.5, U3.6; also elsewhere on the board
/SCL: U3.4; also elsewhere on the board
/SDA: U3.3; also elsewhere on the board
/VCC: U3.2; also elsewhere on the board

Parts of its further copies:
U1, U2, U4, U5, U6, U7, U8, U9, U10: BX-HY2.0-4PWT; CONN-SMD_4P-P2.0_BX-HY2.0-4PWT; LCSC Part C18077773

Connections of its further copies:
/GND: U1.1, U1.5, U1.6, U2.1, U2.5, U2.6, U4.1, U4.5, U4.6, U5.1, U5.5, U5.6, U6.1, U6.5, U6.6, U7.1, U7.5, U7.6, U8.1, U8.5, U8.6, U9.1, U9.5, U9.6, U10.1, U10.5, U10.6; also elsewhere on the board
/SCL: U1.4, U2.4, U4.4, U5.4, U6.4, U7.4, U8.4, U9.4, U10.4; also elsewhere on the board
/SDA: U1.3, U2.3, U4.3, U5.3, U6.3, U7.3, U8.3, U9.3, U10.3; also elsewhere on the board
/VCC: U1.2, U2.2, U4.2, U5.2, U6.2, U7.2, U8.2, U9.2, U10.2; also elsewhere on the board


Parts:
USB1: 10.0 QTJ6.3; USB-A-SMD_10.0-QTJ6.3; LCSC Part C404966

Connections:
/GND: USB1.4 (GND), USB1.5, USB1.6, USB1.7, USB1.8; also elsewhere on the board
/SCL: USB1.3 (D+); also elsewhere on the board
/SDA: USB1.2 (D-); also elsewhere on the board
/VCC: USB1.1 (VCC); also elsewhere on the board


Board: 2 copper layers, 25.0 x 84.9 mm, 14 parts (0 on the bottom side), 4 nets.

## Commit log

2025-03-20 add 3D model data
    [chip-10.stl, chip-flat.stl, hub-bottom.stl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]
2025-03-27 fix via.json for encoders
2026-03-25 update to v2
    [chip-10.stl, chip-flat.stl, hub-bottom.stl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]
2026-03-31 Update build guide with assembly details and tips (#27)
    Added details about starter set components and cable management for assembly.
2026-07-30 add v1 circuits (#32)
    [HY_Connector.kicad_sch, Hub.kicad_pcb, Hub.kicad_sch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]
2026-08-08 Add firmware writing instructions to guide (#33)
    Added instructions for firmware writing process, including details on the rst button and file transfer.
